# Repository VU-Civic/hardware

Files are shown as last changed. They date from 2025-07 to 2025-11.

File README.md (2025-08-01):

# CivicAlert Hardware Design Repository

This repository contains hardware design files for the CivicAlert sensor device. The design was created
using [KiCad](https://www.kicad.org/download) and requires v9.0.0 or later to open and edit.

The CivicAlert gunshot sensor is a self-contained PCB which utilizes four audio channels, a digital
compass and IMU, GNSS satellite data, and a state-of-the-art AI-based classification model to detect
gunshots in its vicinity. Relevant event information and evidential audio clips can be transferred to
a cloud server for futher processing using a dedicated cellular-based Internet of Things (IoT) network.

## Getting Started

1. Clone this repo on your local machine
2. Download and install [KiCad](https://www.kicad.org/download)
3. Open KiCad
4. Click `File->Open Project`
5. Select `hw.kicad_pro` from the repo root directory

You will be presented with a listing of available KiCad tools for this project. The two most relevant are
the "Schematic Editor" and the "PCB Editor". The Schematic Editor allows you to view and manipulate the
logical connections between hardware components and power networks, while the "PCB Editor" allows you to
view the actual design of the board and layout of the components as they will be placed during
manufacturing and assembly.

The schematic symbols and footprints for all parts and components used in this design have been stored
within the repo itself and should automatically be picked up by KiCad when you open the project. If you
would like to add new parts or alter existing ones, you may use the "Symbol Editor" or "Footprint
Editor" tool, and ensure that any new parts are stored in either `part_symbols/` or `part_footprints/`
so that new parts will be visible and available to others in the future.

Additionally, 3D CAD models for all parts can be found in `part_3d_cads/`, which will be used by KiCad
to generate a 3D rendering of the final assembled board. Finally, all datasheets, application notes,
and relevant part-specific documentation can be in the `datasheets/` folder.

## Revisions

### Revision A
*Release Date: 03-13-2025*

Original prototype version of the hardware. Expected usage includes:

* 4 audio channels to allow computation of 3D angles of arrival
* Digital compass + IMU to align angles of arrival with a global coordinate system
* Multi-constellation GNSS receiver to ensure accurate timestamping in difficult environments
* Micro-SIM card to provide direct connectivity to Thingstream for cellular data offloading
* Event detection and angle of arrival calculations performed on primary MCU
* Event classification and validation performed using AI models on external Raspberry Pi
* Data communication between primary MCU and Raspberry Pi uses USB over internal connector
* Data communication between primary MCU and external debugging machine (PC) uses USB-C connector
* Internal switch automatically routes primary MCU output to correct USB interface depending on the
  presence or absence of a connected Raspberry Pi Compute Module
* Entire board (including Raspberry Pi) is powered from a 5V USB-C cable
* Firmware flashing requires an open-ended card edge connector from
  [Kyocera AVX](https://www.digikey.com/en/products/detail/kyocera-avx/009159010061911/11307835)
  and an STLink-V3MINIE programmer from
  [STMicroelectronics](https://www.digikey.com/en/products/detail/stmicroelectronics/STLINK-V3MINIE/16284301)

Major functionality and components are shown below:

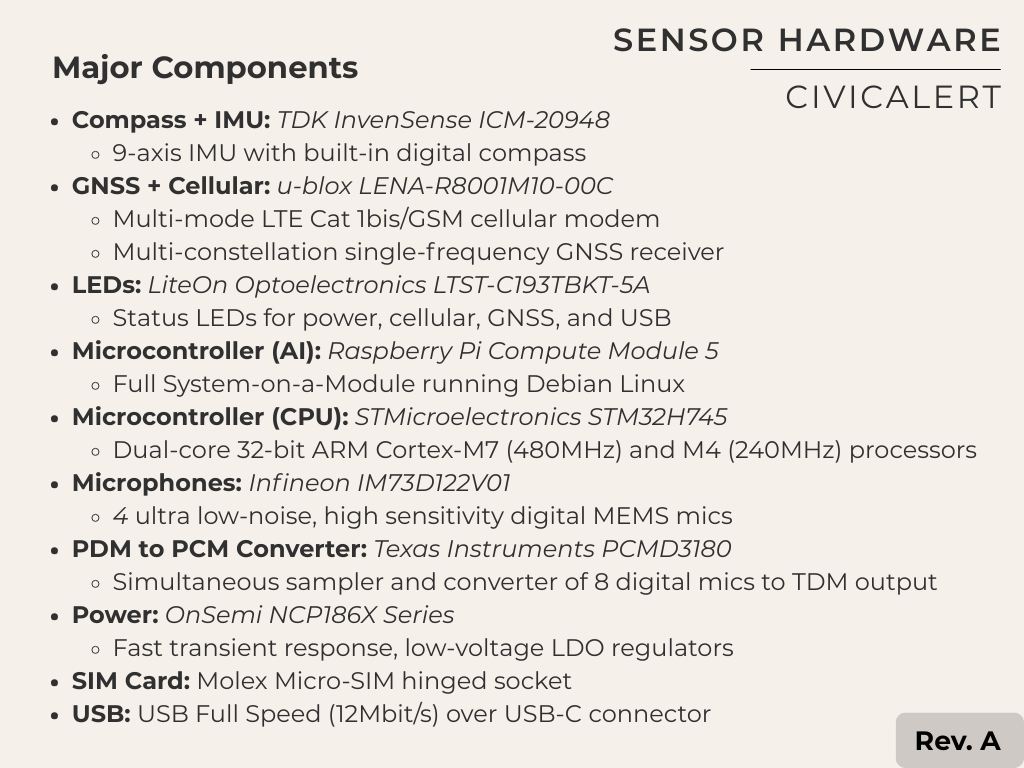
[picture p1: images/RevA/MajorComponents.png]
Rev. A Major Components

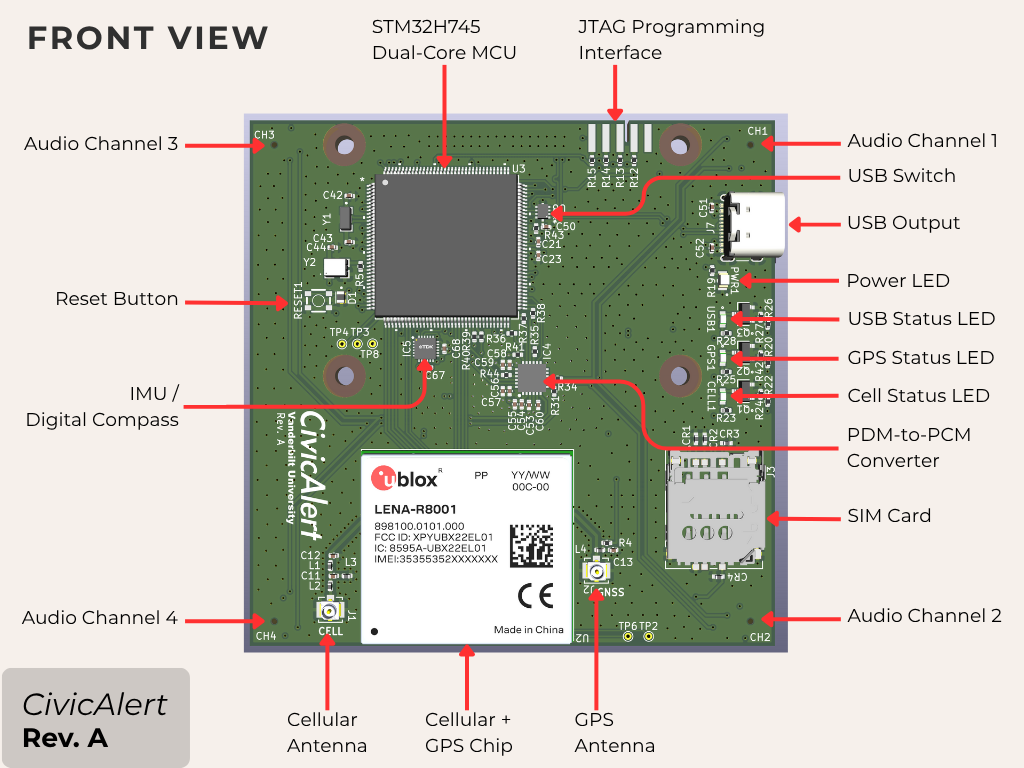
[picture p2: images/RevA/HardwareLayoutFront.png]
Rev. A Board Front

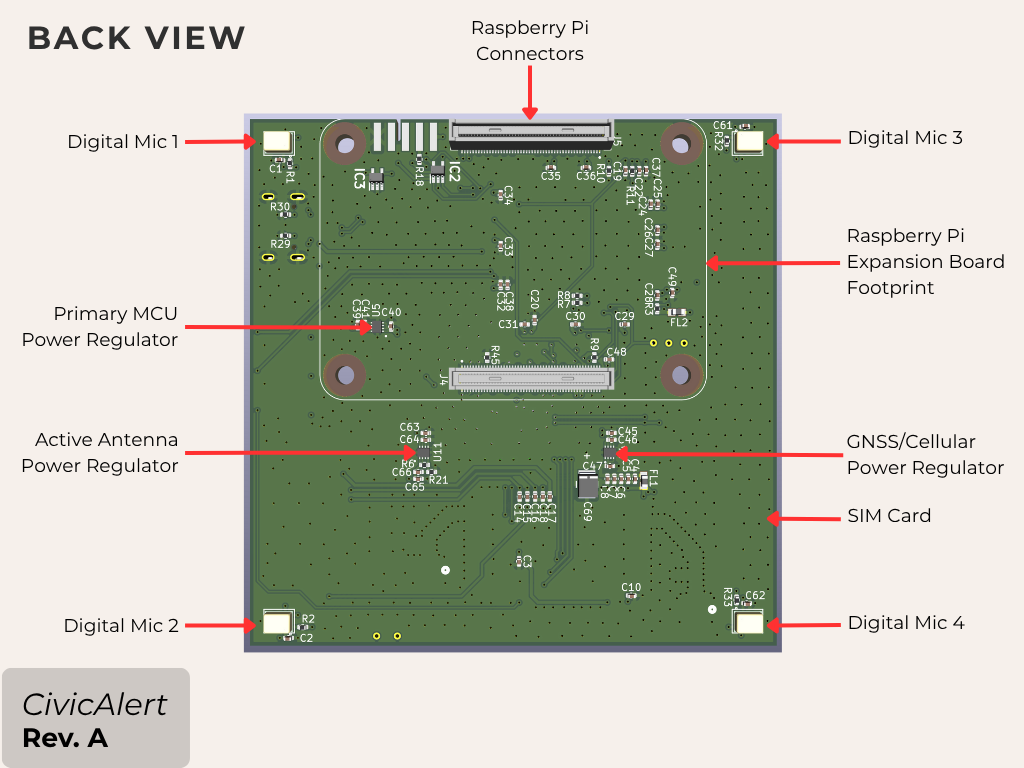
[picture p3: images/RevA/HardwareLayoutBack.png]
Rev. A Major Back Rev. A Board Back


### Revision B
*Release Date: 08-01-2025*

Updated to support edge-based AI and remove the need for an external Raspberry Pi Compute Module:

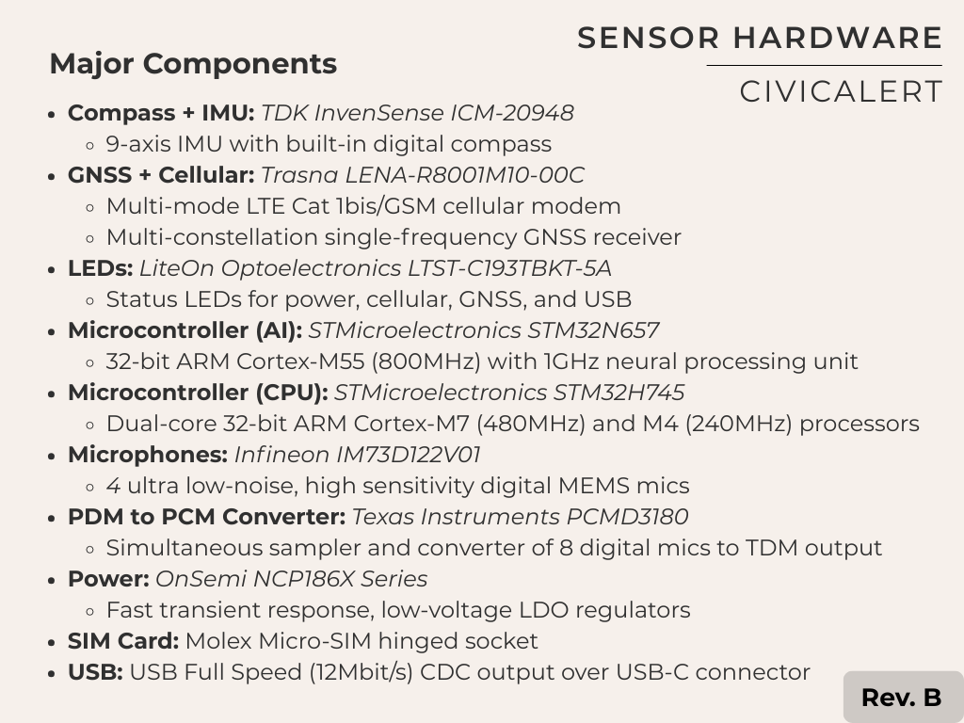
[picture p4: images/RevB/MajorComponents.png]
Rev. B Major Components

TODO: Board Designs

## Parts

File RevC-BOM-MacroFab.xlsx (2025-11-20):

Designator | Value | Footprint | Populate | MPN | Manufacturer | MPN | Manufacturer
BOOT1 | PTS810 | PTS810 | 1 | MF-SW-TACT-4.2MM | MacroFab
C1 | 6.8p | C_0402_1005Metric | 1 | GCM1555C1H6R8BA16J | Murata
C10 | 10u | C_0805_2012Metric | 1 | CGA4J1X7R0J106M125AC | TDK
C100 | 1.5p | C_0402_1005Metric | 1 | GRT1555C1H1R5CA02J | Murata
C101 | 0.5p | C_0402_1005Metric | 1 | GJM1555C1HR50WB01D | Murata
C102 | T520B337M006ATE040 | T520B337M006ATE040 | 1 | T520B337M006ATE040 | KEMET
C103 | 8.2p | C_0402_1005Metric | 1 | GRM1555C1E8R2CA01D | Murata | MF-CAP-0402-8.2pF | MacroFab
C104 | 15p | C_0402_1005Metric | 1 | GRT1555C1H150JA02J | Murata
C105 | 82p | C_0402_1005Metric | 1 | GRT1555C1H820FA02D | Murata
C106 | 10n | C_0402_1005Metric | 1 | GCM155R71H103KA55D | Murata
C107 | 0.1u | C_0402_1005Metric | 1 | GRM155R71C104KA88J | Murata | MF-CAP-0402-0.1uF | MacroFab
C108 | 0.1u | C_0402_1005Metric | 1 | GRM155R71C104KA88J | Murata | MF-CAP-0402-0.1uF | MacroFab
C109 | 0.1u | C_0402_1005Metric | 1 | GRM155R71C104KA88J | Murata | MF-CAP-0402-0.1uF | MacroFab
C11 | 10u | C_0805_2012Metric | 1 | CGA4J1X7R0J106M125AC | TDK
C110 | 0.1u | C_0402_1005Metric | 1 | GRM155R71C104KA88J | Murata | MF-CAP-0402-0.1uF | MacroFab
C111 | 0.1u | C_0402_1005Metric | 1 | GRM155R71C104KA88J | Murata | MF-CAP-0402-0.1uF | MacroFab
C112 | 0.1u | C_0402_1005Metric | 1 | GRM155R71C104KA88J | Murata | MF-CAP-0402-0.1uF | MacroFab
C113 | 10u | C_0603_1608Metric | 1 | GRM188Z71A106KA73D | Murata
C114 | 2.2u | C_0402_1005Metric | 1 | GRT155C71A225KE13D | Murata
C115 | 10u | C_0603_1608Metric | 1 | GRM188Z71A106KA73D | Murata
C116 | 0.1u | C_0402_1005Metric | 1 | GRM155R71C104KA88J | Murata | MF-CAP-0402-0.1uF | MacroFab
C117 | 0.1u | C_0402_1005Metric | 1 | GRM155R71C104KA88J | Murata | MF-CAP-0402-0.1uF | MacroFab
C118 | 10u | C_0603_1608Metric | 1 | GRM188Z71A106KA73D | Murata
C119 | 10u | C_0603_1608Metric | 1 | GRM188Z71A106KA73D | Murata
C12 | 10u | C_0805_2012Metric | 1 | CGA4J1X7R0J106M125AC | TDK
C120 | 0.1u | C_0402_1005Metric | 1 | GRM155R71C104KA88J | Murata | MF-CAP-0402-0.1uF | MacroFab
C121 | 10u | C_0603_1608Metric | 1 | GRM188Z71A106KA73D | Murata
C13 | 1n | C_0402_1005Metric | 1 | GRM155R71H102JA01J | Murata | MF-CAP-0402-1nF | MacroFab
C14 | 10u | C_0603_1608Metric | 1 | GRM188Z71A106KA73D | Murata
C15 | 10u | C_0603_1608Metric | 1 | GRM188Z71A106KA73D | Murata
C16 | 0.1u | C_0402_1005Metric | 1 | GRM155R71C104KA88J | Murata | MF-CAP-0402-0.1uF | MacroFab
C17 | 10u | C_0603_1608Metric | 1 | GRM188Z71A106KA73D | Murata
C18 | 0.1u | C_0402_1005Metric | 1 | GRM155R71C104KA88J | Murata | MF-CAP-0402-0.1uF | MacroFab
C19 | 10u | C_0603_1608Metric | 1 | GRM188Z71A106KA73D | Murata
C2 | 4.7p | C_0402_1005Metric | 1 | GCM1555C1H4R7CA16D | Murata
C20 | 10u | C_0603_1608Metric | 1 | GRM188Z71A106KA73D | Murata
C21 | 0.1u | C_0402_1005Metric | 1 | GRM155R71C104KA88J | Murata | MF-CAP-0402-0.1uF | MacroFab
C22 | 10u | C_0603_1608Metric | 1 | GRM188Z71A106KA73D | Murata
C23 | 10u | C_0603_1608Metric | 1 | GRM188Z71A106KA73D | Murata
C24 | 0.1u | C_0402_1005Metric | 1 | GRM155R71C104KA88J | Murata | MF-CAP-0402-0.1uF | MacroFab
C25 | 10u | C_0603_1608Metric | 1 | GRM188Z71A106KA73D | Murata
C26 | 0.1u | C_0201_0603Metric | 1 | GRM033Z71C104KE14D | Murata
C27 | 0.1u | C_0201_0603Metric | 1 | GRM033Z71C104KE14D | Murata
C28 | 0.1u | C_0201_0603Metric | 1 | GRM033Z71C104KE14D | Murata
C29 | 0.1u | C_0201_0603Metric | 1 | GRM033Z71C104KE14D | Murata
C3 | 10u | C_0805_2012Metric | 1 | CGA4J1X7R0J106M125AC | TDK
C30 | 2.2u | C_0201_0603Metric | 1 | GRT033D70J105ME13D | Murata
C31 | 0.1u | C_0201_0603Metric | 1 | GRM033Z71C104KE14D | Murata
C32 | 0.1u | C_0201_0603Metric | 1 | GRM033Z71C104KE14D | Murata
C33 | 0.1u | C_0201_0603Metric | 1 | GRM033Z71C104KE14D | Murata
C34 | 0.1u | C_0201_0603Metric | 1 | GRM033Z71C104KE14D | Murata
C35 | 0.1u | C_0201_0603Metric | 1 | GRM033Z71C104KE14D | Murata
C36 | 0.1u | C_0201_0603Metric | 1 | GRM033Z71C104KE14D | Murata
C37 | 0.1u | C_0201_0603Metric | 1 | GRM033Z71C104KE14D | Murata
C38 | 0.1u | C_0201_0603Metric | 1 | GRM033Z71C104KE14D | Murata
C39 | 2.2u | C_0201_0603Metric | 1 | GRT033D70J105ME13D | Murata
C4 | 10u | C_0805_2012Metric | 1 | CGA4J1X7R0J106M125AC | TDK
C40 | 2.2u | C_0201_0603Metric | 1 | GRT033D70J105ME13D | Murata
C41 | 2.2u | C_0201_0603Metric | 1 | GRT033D70J105ME13D | Murata
C42 | 2.2u | C_0201_0603Metric | 1 | GRT033D70J105ME13D | Murata
C43 | 2.2u | C_0201_0603Metric | 1 | GRT033D70J105ME13D | Murata
C44 | 4.7u | C_0402_1005Metric | 1 | GRT155D70J475ME13D | Murata
C45 | 0.1u | C_0201_0603Metric | 1 | GRM033Z71C104KE14D | Murata
C46 | 0.1u | C_0201_0603Metric | 1 | GRM033Z71C104KE14D | Murata
C5 | 10u | C_0805_2012Metric | 1 | CGA4J1X7R0J106M125AC | TDK
C51 | 0.1u | C_0402_1005Metric | 1 | GRM155R71C104KA88J | Murata | MF-CAP-0402-0.1uF | MacroFab
C52 | 4.7u | C_0402_1005Metric | 1 | GRT155D70J475ME13D | Murata
C53 | 4.7u | C_0402_1005Metric | 1 | GRT155D70J475ME13D | Murata
C54 | 0.1u | C_0402_1005Metric | 1 | GRM155R71C104KA88J | Murata | MF-CAP-0402-0.1uF | MacroFab
C55 | 0.1u | C_0402_1005Metric | 1 | GRM155R71C104KA88J | Murata | MF-CAP-0402-0.1uF | MacroFab
C56 | 4.7u | C_0402_1005Metric | 1 | GRT155D70J475ME13D | Murata
C57 | 0.1u | C_0402_1005Metric | 1 | GRM155R71C104KA88J | Murata | MF-CAP-0402-0.1uF | MacroFab
C58 | 10u | C_0603_1608Metric | 1 | GRM188Z71A106KA73D | Murata
C59 | 0.1u | C_0402_1005Metric | 1 | GRM155R71C104KA88J | Murata | MF-CAP-0402-0.1uF | MacroFab
C6 | 47u | C_1206_3216Metric | 1 | C3216X7S0J476M160AC | TDK
C60 | 2.2u | C_0402_1005Metric | 1 | GRT155C71A225KE13D | Murata
C61 | 10u | C_0603_1608Metric | 1 | GRM188Z71A106KA73D | Murata
C62 | 4.7u | C_0402_1005Metric | 1 | GRT155D70J475ME13D | Murata
C63 | 0.1u | C_0402_1005Metric | 1 | GRM155R71C104KA88J | Murata | MF-CAP-0402-0.1uF | MacroFab
C64 | 0.1u | C_0402_1005Metric | 1 | GRM155R71C104KA88J | Murata | MF-CAP-0402-0.1uF | MacroFab
C65 | 0.1u | C_0402_1005Metric | 1 | GRM155R71C104KA88J | Murata | MF-CAP-0402-0.1uF | MacroFab
C66 | 0.1u | C_0402_1005Metric | 1 | GRM155R71C104KA88J | Murata | MF-CAP-0402-0.1uF | MacroFab
C67 | 0.1u | C_0402_1005Metric | 1 | GRM155R71C104KA88J | Murata | MF-CAP-0402-0.1uF | MacroFab
C68 | 0.1u | C_0402_1005Metric | 1 | GRM155R71C104KA88J | Murata | MF-CAP-0402-0.1uF | MacroFab
C69 | 0.1u | C_0402_1005Metric | 1 | GRM155R71C104KA88J | Murata | MF-CAP-0402-0.1uF | MacroFab
C7 | 10u | C_0805_2012Metric | 1 | CGA4J1X7R0J106M125AC | TDK
C70 | 0.1u | C_0402_1005Metric | 1 | GRM155R71C104KA88J | Murata | MF-CAP-0402-0.1uF | MacroFab
C71 | 0.1u | C_0402_1005Metric | 1 | GRM155R71C104KA88J | Murata | MF-CAP-0402-0.1uF | MacroFab
C72 | 0.1u | C_0402_1005Metric | 1 | GRM155R71C104KA88J | Murata | MF-CAP-0402-0.1uF | MacroFab
C73 | 0.1u | C_0402_1005Metric | 1 | GRM155R71C104KA88J | Murata | MF-CAP-0402-0.1uF | MacroFab
C74 | 0.1u | C_0402_1005Metric | 1 | GRM155R71C104KA88J | Murata | MF-CAP-0402-0.1uF | MacroFab
C75 | 0.1u | C_0402_1005Metric | 1 | GRM155R71C104KA88J | Murata | MF-CAP-0402-0.1uF | MacroFab
C76 | 4.7u | C_0402_1005Metric | 1 | GRT155D70J475ME13D | Murata
C77 | 0.1u | C_0402_1005Metric | 1 | GRM155R71C104KA88J | Murata | MF-CAP-0402-0.1uF | MacroFab
C78 | 2.2u | C_0402_1005Metric | 1 | GRT155C71A225KE13D | Murata
C79 | 4.7u | C_0402_1005Metric | 1 | GRT155D70J475ME13D | Murata
C8 | 47u | C_1206_3216Metric | 1 | C3216X7S0J476M160AC | TDK
C80 | 2.2u | C_0402_1005Metric | 1 | GRT155C71A225KE13D | Murata
C81 | 2.2u | C_0402_1005Metric | 1 | GRT155C71A225KE13D | Murata
C82 | 10n | C_0402_1005Metric | 1 | GCM155R71H103KA55D | Murata
C83 | 0.1u | C_0402_1005Metric | 1 | GRM155R71C104KA88J | Murata | MF-CAP-0402-0.1uF | MacroFab
C84 | 3.3p | C_0402_1005Metric | 1 | GRT1555C1H3R3CA02J | Murata
C85 | 0.1u | C_0402_1005Metric | 1 | GRM155R71C104KA88J | Murata | MF-CAP-0402-0.1uF | MacroFab
C86 | 3.3p | C_0402_1005Metric | 1 | GRT1555C1H3R3CA02J | Murata
C87 | 0.1u | C_0402_1005Metric | 1 | GRM155R71C104KA88J | Murata | MF-CAP-0402-0.1uF | MacroFab
C88 | 0.1u | C_0402_1005Metric | 1 | GRM155R71C104KA88J | Murata | MF-CAP-0402-0.1uF | MacroFab
C89 | 0.1u | C_0402_1005Metric | 1 | GRM155R71C104KA88J | Murata | MF-CAP-0402-0.1uF | MacroFab
C9 | 10u | C_0805_2012Metric | 1 | CGA4J1X7R0J106M125AC | TDK
C90 | 0.1u | C_0402_1005Metric | 1 | GRM155R71C104KA88J | Murata | MF-CAP-0402-0.1uF | MacroFab
C91 | 0.1u | C_0402_1005Metric | 1 | GRM155R71C104KA88J | Murata | MF-CAP-0402-0.1uF | MacroFab
C92 | 0.1u | C_0402_1005Metric | 1 | GRM155R71C104KA88J | Murata | MF-CAP-0402-0.1uF | MacroFab
C93 | 0.1u | C_0402_1005Metric | 1 | GRM155R71C104KA88J | Murata | MF-CAP-0402-0.1uF | MacroFab
C94 | 0.1u | C_0402_1005Metric | 1 | GRM155R71C104KA88J | Murata | MF-CAP-0402-0.1uF | MacroFab
C95 | 47p | C_0402_1005Metric | 1 | GRT1555C1H470JA02J | Murata
C96 | 47p | C_0402_1005Metric | 1 | GRT1555C1H470JA02J | Murata
C97 | 47p | C_0402_1005Metric | 1 | GRT1555C1H470JA02J | Murata
C98 | 47p | C_0402_1005Metric | 1 | GRT1555C1H470JA02J | Murata
C99 | 0.1u | C_0402_1005Metric | 1 | GRM155R71C104KA88J | Murata | MF-CAP-0402-0.1uF | MacroFab
CELL1 | LTST-C190KGKT | LTST-C190KGKT | 1 | MF-LED-0603-GREEN | MacroFab
CELL2 | RECE.20279.001E.01 | RECE.20279.001E.01 | 1 | RECE.20279.001E.01 | Taoglas
CH1 | SPK11R1LM4H-1 | SPK11R1LM4H-1 | 1 | SPK11R1LM4H-1 | Syntiant
CH2 | SPK11R1LM4H-1 | SPK11R1LM4H-1 | 1 | SPK11R1LM4H-1 | Syntiant
CH3 | SPK11R1LM4H-1 | SPK11R1LM4H-1 | 1 | SPK11R1LM4H-1 | Syntiant
CH4 | SPK11R1LM4H-1 | SPK11R1LM4H-1 | 1 | SPK11R1LM4H-1 | Syntiant
CR1 | BAT854W,115 | BAT854AW,115 | 1 | BAT854W,115 | Nexperia
CR2 | PESD0402-140 | PESD0402-140_LTF | 1 | PESD0402-140 | Littelfuse
CR3 | PESD0402-140 | PESD0402-140_LTF | 1 | PESD0402-140 | Littelfuse
CR4 | PESD0402-140 | PESD0402-140_LTF | 1 | PESD0402-140 | Littelfuse
CR5 | PESD0402-140 | PESD0402-140_LTF | 1 | PESD0402-140 | Littelfuse
CR6 | BAT854W,115 | BAT854AW,115 | 1 | BAT854W,115 | Nexperia
FL1 | FCM 1608KF-601T03 | FCM1608KF-601T03 | 1 | FCM 1608KF-601T03 | Tai Tech
FL2 | BLM18EG221SN1D | BLM18EG221SN1D | 1 | BLM18EG221SN1D | Murata
GNSS1 | RECE.20279.001E.01 | RECE.20279.001E.01 | 1 | RECE.20279.001E.01 | Taoglas
GPS1 | LTST-C190KGKT | LTST-C190KGKT | 1 | MF-LED-0603-GREEN | MacroFab
IC1 | MX25UM25645GXDI00-T | MX25UM25645GXDI00 | 1 | MX25UM25645GXDI00-T | Macronix
IC2 | ESDALC6V1W5 | ESDALC6V1W5 | 1 | ESDALC6V1W5 | STMicroelectronics
IC3 | ESDALC6V1W5 | ESDALC6V1W5 | 1 | ESDALC6V1W5 | STMicroelectronics
IC4 | ICM-20948 | ICM-20948 | 1 | ICM-20948 | InvenSense
J1 | USB4730-GF-A_REVA | USB4730-GF-A | 1 | USB4730-GF-A-KIT | Global Connector Technology
J2 | 78800-0001 | 0788000001 | 1 | 78800-0001 | Molex
L1 | IHLP1212BZERR88M11 | IHLP1212BZERR88M11 | 1 | IHLP1212BZERR88M11 | Vishay
L2 | IHLP1212BZER1R5M11 | IHLP1212BZER1R5M11 | 1 | IHLP1212BZER1R5M11 | Vishay
L3 | 120n | L_0402_1005Metric | 1 | LQW15ANR12J00 | Murata | LQW15ANR12J00D | Murata
L4 | 3.4n | L_0402_1005Metric | 1 | LQG15WZ3N4S02D | Murata
L5 | 2.7n | L_0402_1005Metric | 1 | LQG15HS2N7B02D | Murata
L6 | 1.2n | L_0402_1005Metric | 1 | LQG15HS1N2B02D | Murata
PWR1 | LTST-C190KGKT | LTST-C190KGKT | 1 | MF-LED-0603-GREEN | MacroFab
Q3 | MMBT3904LT3G | MMBT3904LT3G | 1 | BC847CE6327HTSA1 | Infineon
Q4 | MMBT3904LT3G | MMBT3904LT3G | 1 | BC847CE6327HTSA1 | Infineon
R10 | 300 | R_0402_1005Metric | 1 | MF-RES-0402-330 | MacroFab
R11 | 10k | R_0402_1005Metric | 1 | MF-RES-0402-10K | MacroFab
R12 | 22 | R_0402_1005Metric | 1 | MF-RES-0402-22 | MacroFab
R13 | 10k | R_0402_1005Metric | 1 | MF-RES-0402-10K | MacroFab
R14 | 10k | R_0402_1005Metric | 1 | MF-RES-0402-10K | MacroFab
R15 | 10k | R_0402_1005Metric | 1 | MF-RES-0402-10K | MacroFab
R16 | 10k | R_0402_1005Metric | 1 | MF-RES-0402-10K | MacroFab
R17 | 10k | R_0402_1005Metric | 1 | MF-RES-0402-10K | MacroFab
R18 | 22 | R_0402_1005Metric | 1 | MF-RES-0402-22 | MacroFab
R19 | 22 | R_0402_1005Metric | 1 | MF-RES-0402-22 | MacroFab
R20 | 47k | R_0402_1005Metric | 1 | CRGCQ0402F47K | TE Connectivity
R21 | 10k | R_0402_1005Metric | 1 | MF-RES-0402-10K | MacroFab
R22 | 47k | R_0402_1005Metric | 1 | CRGCQ0402F47K | TE Connectivity
R23 | 47k | R_0402_1005Metric | 1 | CRGCQ0402F47K | TE Connectivity
R24 | 47k | R_0402_1005Metric | 1 | CRGCQ0402F47K | TE Connectivity
R25 | 47k | R_0402_1005Metric | 1 | CRGCQ0402F47K | TE Connectivity
R26 | 100k | R_0402_1005Metric | 1 | MF-RES-0402-100K | MacroFab
R27 | 10k | R_0402_1005Metric | 1 | MF-RES-0402-10K | MacroFab
R28 | 47 | R_0402_1005Metric | 1 | MF-RES-0402-47 | MacroFab
R3 | 226k | R_0603_1608Metric | 1 | RT0603BRD07226KL | Yageo Group
R32 | 22 | R_0402_1005Metric | 1 | MF-RES-0402-22 | MacroFab
R33 | 47 | R_0402_1005Metric | 1 | MF-RES-0402-47 | MacroFab
R34 | 22 | R_0402_1005Metric | 1 | MF-RES-0402-22 | MacroFab
R35 | 47 | R_0402_1005Metric | 1 | MF-RES-0402-47 | MacroFab
R36 | 10k | R_0402_1005Metric | 1 | MF-RES-0402-10K | MacroFab
R37 | 10k | R_0402_1005Metric | 1 | MF-RES-0402-10K | MacroFab
R38 | 22 | R_0402_1005Metric | 1 | MF-RES-0402-22 | MacroFab
R39 | 22 | R_0402_1005Metric | 1 | MF-RES-0402-22 | MacroFab
R40 | 22 | R_0402_1005Metric | 1 | MF-RES-0402-22 | MacroFab
R41 | 5.1k | R_0402_1005Metric | 1 | RC0402FR-075K1L | Yageo Group
R42 | 5.1k | R_0402_1005Metric | 1 | RC0402FR-075K1L | Yageo Group
R43 | 2.2k | R_0402_1005Metric | 1 | 3-1622826-1 | TE Connectivity / AMP | CR0402-FX-2201GLF | Bourns
R44 | 2.2k | R_0402_1005Metric | 1 | 3-1622826-1 | TE Connectivity / AMP | CR0402-FX-2201GLF | Bourns
R45 | 10k | R_0402_1005Metric | 1 | MF-RES-0402-10K | MacroFab
R46 | 300 | R_0402_1005Metric | 1 | MF-RES-0402-330 | MacroFab
R47 | 10k | R_0402_1005Metric | 1 | MF-RES-0402-10K | MacroFab
R48 | 47k | R_0402_1005Metric | 1 | CRGCQ0402F47K | TE Connectivity
R49 | 33 | R_0402_1005Metric | 1 | AC0402JR-0733RL | Yageo Group
R5 | 143k | R_0603_1608Metric | 1 | RT0603BRD07140KL | Yageo Group
R50 | 300 | R_0402_1005Metric | 1 | MF-RES-0402-330 | MacroFab
R51 | 10k | R_0402_1005Metric | 1 | MF-RES-0402-10K | MacroFab
R52 | 47k | R_0402_1005Metric | 1 | CRGCQ0402F47K | TE Connectivity
R53 | 47 | R_0402_1005Metric | 1 | MF-RES-0402-47 | MacroFab
R54 | 47 | R_0402_1005Metric | 1 | MF-RES-0402-47 | MacroFab
R55 | 47 | R_0402_1005Metric | 1 | MF-RES-0402-47 | MacroFab
R56 | 47 | R_0402_1005Metric | 1 | MF-RES-0402-47 | MacroFab
R57 | 47 | R_0402_1005Metric | 1 | MF-RES-0402-47 | MacroFab
R58 | 22 | R_0402_1005Metric | 1 | MF-RES-0402-22 | MacroFab
R59 | 22 | R_0402_1005Metric | 1 | MF-RES-0402-22 | MacroFab
R6 | 97.6k | R_0603_1608Metric | 1 | RT0603BRD0797K6L | Yageo Group
R60 | 2.2k | R_0402_1005Metric | 1 | 3-1622826-1 | TE Connectivity / AMP | CR0402-FX-2201GLF | Bourns
R61 | 2.2k | R_0402_1005Metric | 1 | 3-1622826-1 | TE Connectivity / AMP | CR0402-FX-2201GLF | Bourns
R62 | 10k | R_0402_1005Metric | 1 | MF-RES-0402-10K | MacroFab
R63 | 2.2k | R_0402_1005Metric | 1 | 3-1622826-1 | TE Connectivity / AMP | CR0402-FX-2201GLF | Bourns
R64 | 2.2k | R_0402_1005Metric | 1 | 3-1622826-1 | TE Connectivity / AMP | CR0402-FX-2201GLF | Bourns
R7 | 261k | R_0603_1608Metric | 1 | RT0603BRD07261KL | Yageo Group
R8 | 62k | R_0402_1005Metric | 1 | ERJ-2RKF6202X | Panasonic
R9 | 91k | R_0402_1005Metric | 1 | ERJ-2RKF9102X | Panasonic
SD1 | 15882 | 15882 | 1 | MF-MICROSD | MacroFab
U1 | LTC3315AHV-TRMPBF | LTC3315AHV | 1 | LTC3315AHV#TRMPBF | Analog Devices
U10 | TPS22919DCKR | TPS22919DCKR | 1 | TPS22919DCKR | Texas Instruments
U11 | STM32H745ZIT6 | STM32H745ZIT6 | 1 | STM32H745ZIT6 | STMicroelectronics
U12 | LENA-R8001M10-00C | LENA-R8001M10-00C | 1 | LENA-R8001M10-00C | u-blox
U13 | PCMD3140IRTER | PCMD3140IRTER | 1 | PCMD3140IRTER | Texas Instruments
U14 | NCP186AMX180TAG | NCP186AMX | 1 | NCP186AMX180TAG | onsemi
U2 | NCP186AMX180TAG | NCP186AMX | 1 | NCP186AMX180TAG | onsemi
U3 | NCP186AMX390TAG | NCP186AMX | 1 | NCP186AMX390TAG | onsemi
U4 | NCP186AMX180TAG | NCP186AMX | 1 | NCP186AMX180TAG | onsemi
U5 | NCP186AMX330TAG | NCP186AMX | 1 | NCP186AMX330TAG | onsemi
U6 | STM32N647L0H3Q | STM32N647L0H3Q | 1 | STM32N647L0H3Q | STMicroelectronics
U7 | HSP051-4M10 | HSP051-4M10 | 1 | HSP051-4M10 | STMicroelectronics
U8 | HSP051-4M10 | HSP051-4M10 | 1 | HSP051-4M10 | STMicroelectronics
U9 | NX3L1T3157GMZ | NX3L1T3157GMZ | 1 | NX3L1T3157GMZ | NXP Semiconductors
Y3 | ATX-H11-F-25.000MHz-F25-T | ATX-H11-F-25_000MHz-F25-T | 1 | ATX-H11-F-25.000MHZ-F25-T | Abracon
Y4 | ABS07AIG-32.768KHZ-7-T | ABS07AIG_32_768KHZ_7_T | 1 | ABS07AIG-32.768KHZ-7-T | Abracon

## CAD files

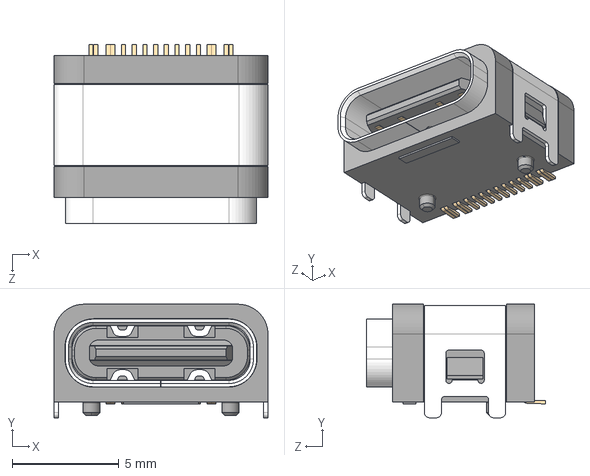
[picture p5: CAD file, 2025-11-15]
part_3d_cads/USB4730-GF-A.step
10.0 x 5.31 x 8.36 mm

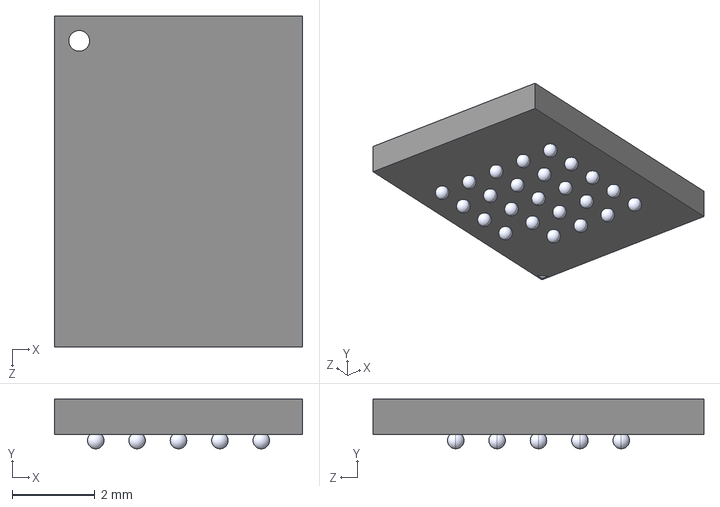
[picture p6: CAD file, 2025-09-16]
part_3d_cads/MX25UM25645GXDI00.step
6.00 x 1.20 x 8.00 mm

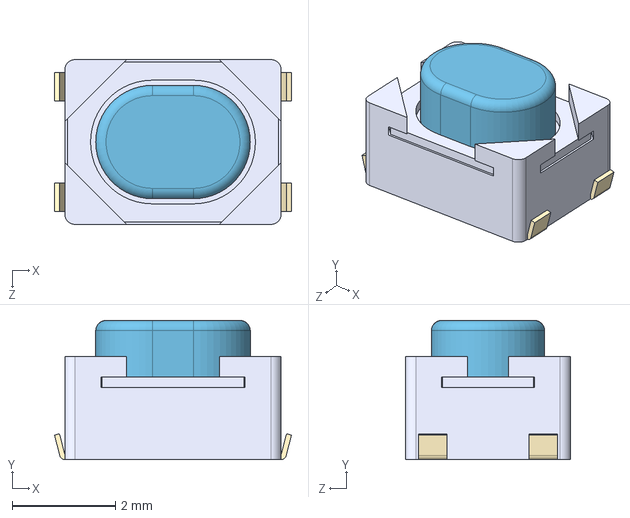
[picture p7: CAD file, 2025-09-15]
part_3d_cads/PTS810S.step
4.60 x 2.70 x 3.20 mm

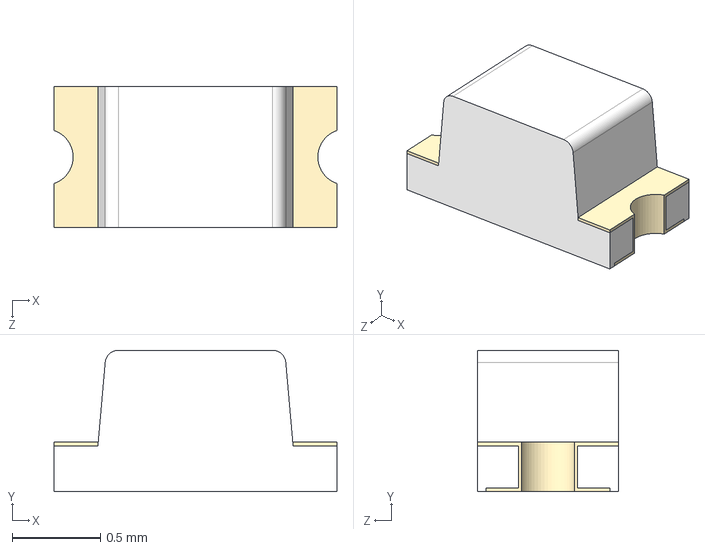
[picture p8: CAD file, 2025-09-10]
part_3d_cads/LTST-C190KGKT.step
1.60 x 0.8 x 0.8 mm

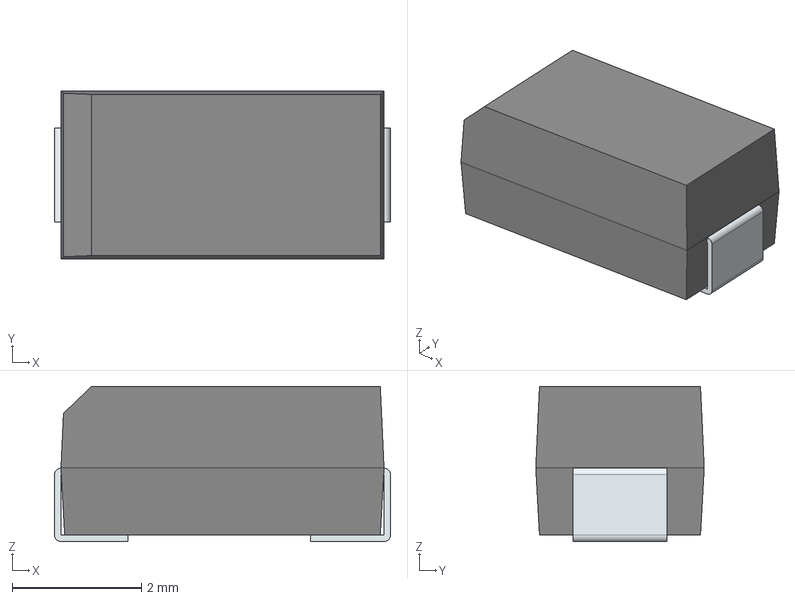
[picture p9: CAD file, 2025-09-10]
part_3d_cads/B140Q-13-F.step
5.20 x 2.60 x 2.40 mm
FilletPin1
FilletPin2

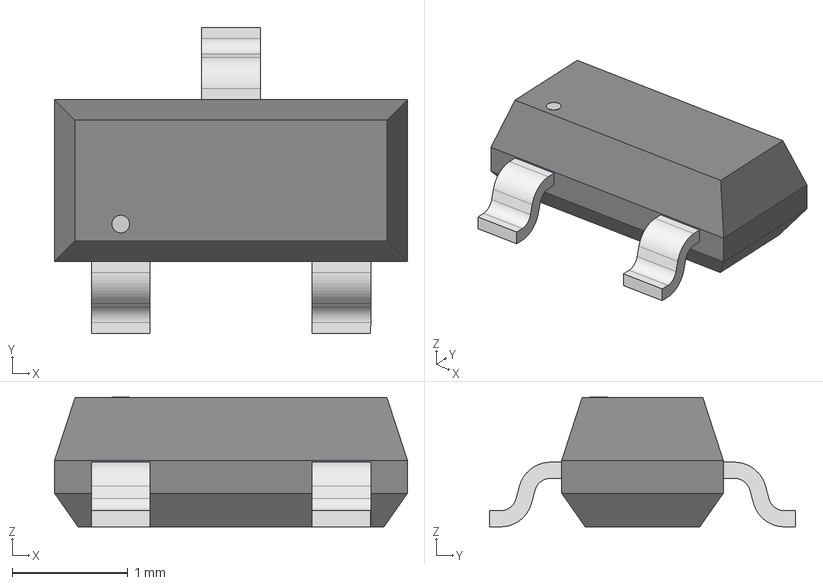
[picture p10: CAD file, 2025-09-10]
part_3d_cads/MMBT3904LT3G.step
3.05 x 2.64 x 1.12 mm

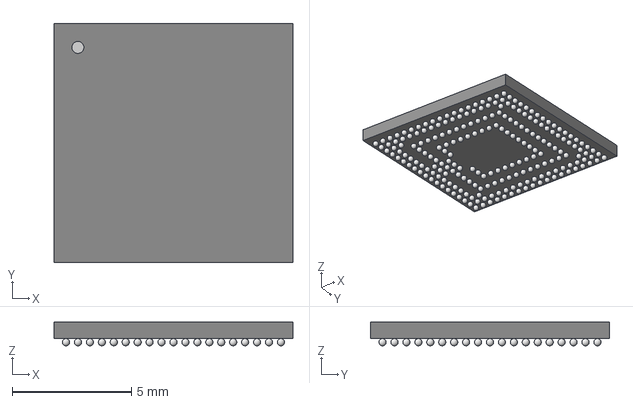
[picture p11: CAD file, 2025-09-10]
part_3d_cads/STM32N647L0H3Q.step
10.0 x 10.0 x 0.993 mm

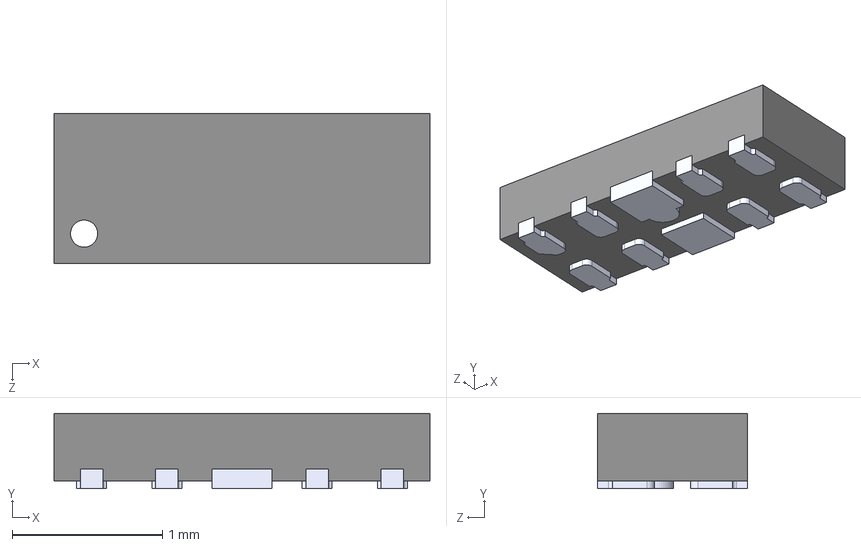
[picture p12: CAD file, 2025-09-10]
part_3d_cads/HSP051-4M10.step
2.50 x 0.5 x 1.00 mm

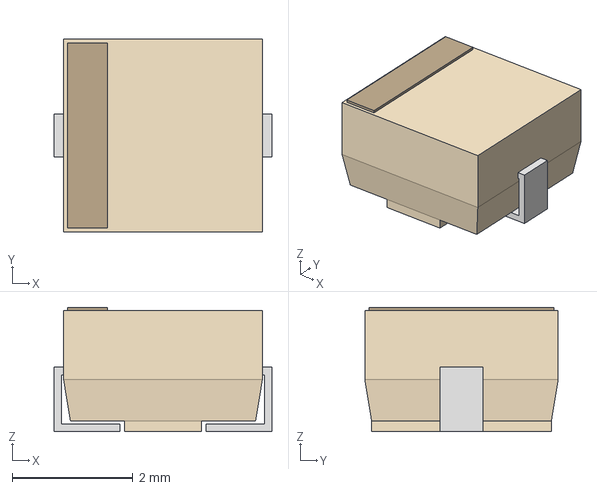
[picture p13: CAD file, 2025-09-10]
part_3d_cads/IHLP1212BZERR88M11.step
3.61 x 3.20 x 2.06 mm

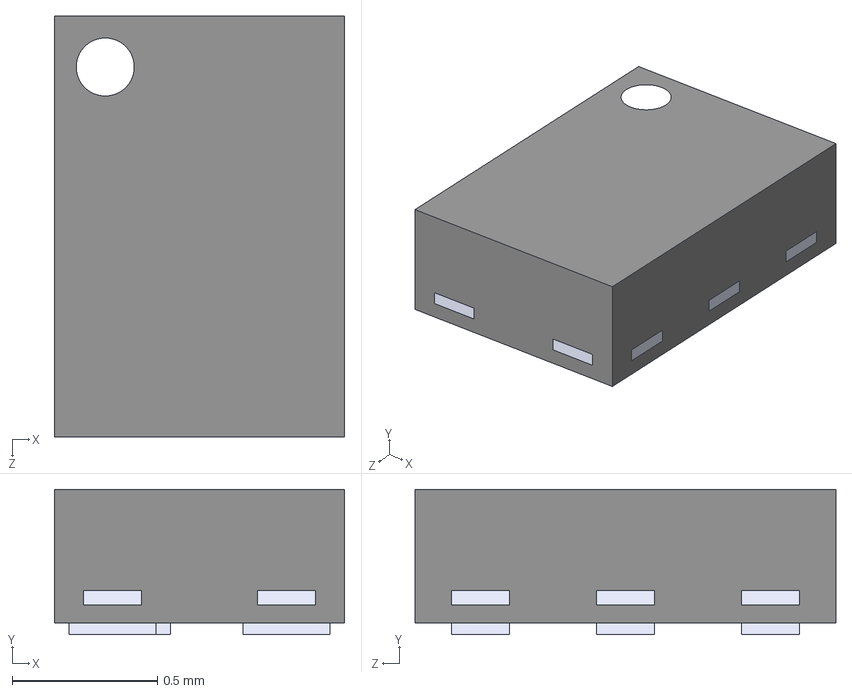
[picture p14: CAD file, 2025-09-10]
part_3d_cads/NX3L1T3157GMZ.step
1 x 0.5 x 1.45 mm

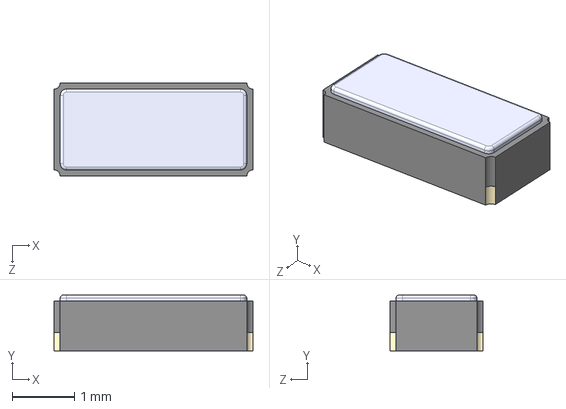
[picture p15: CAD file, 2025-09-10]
part_3d_cads/ABS07AIG-32.768KHZ-7-T.step
3.20 x 0.9 x 1.50 mm

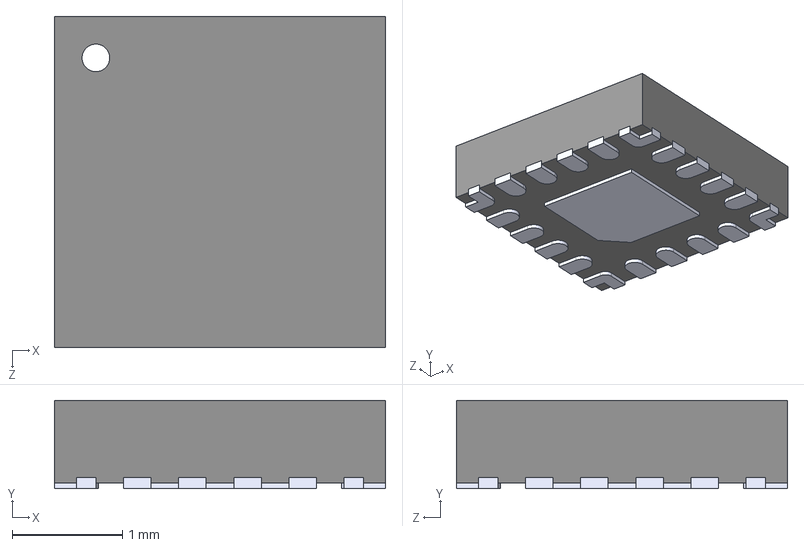
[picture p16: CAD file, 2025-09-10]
part_3d_cads/PCMD3140IRTER.step
3.00 x 0.8 x 3.00 mm

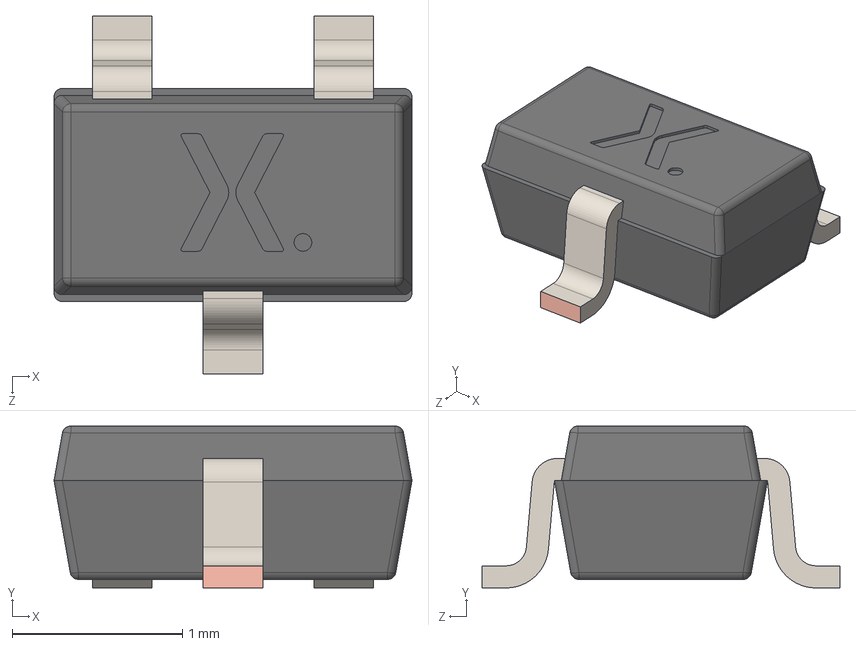
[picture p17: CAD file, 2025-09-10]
part_3d_cads/BAT854AW,115.step
2.10 x 0.95 x 2.10 mm
Upper body
lower body
Lead x 3

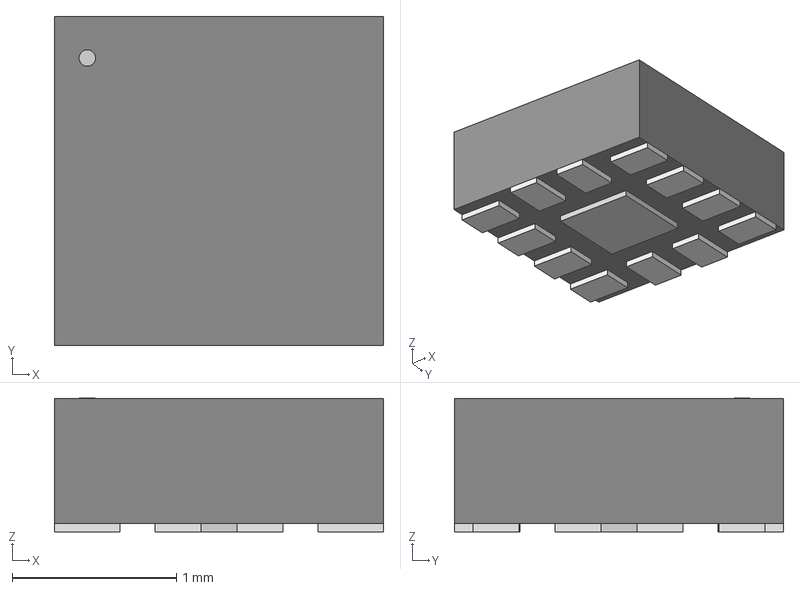
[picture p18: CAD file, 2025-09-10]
part_3d_cads/LTC3315AHV.step
2.01 x 2.01 x 0.815 mm

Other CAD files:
part_3d_cads/IHLP1212BZER1R5M11.step
part_3d_cads/NCP186AMX180TAG.step
part_3d_cads/KC2016Z48.0000C15XXK.step
part_3d_cads/NCP186AMX330TAG.step
part_3d_cads/0788000001.step
part_3d_cads/15882.step
part_3d_cads/ATX-H11-F-25_000MHz-F25-T.step
part_3d_cads/BC847CE6327HTSA1.step
part_3d_cads/BLM18EG221SN1D.step
part_3d_cads/ESDALC6V1W5.step
part_3d_cads/FCM1608KF-601T03.step
part_3d_cads/ICM-20948.step
part_3d_cads/IM73D122V01XTMA1.step
part_3d_cads/NCP186AMX390TAG.step
part_3d_cads/NCP186BMX185TAG.step
part_3d_cads/PESD0402-140_LTF.step
part_3d_cads/RECE.20279.001E.01.step
part_3d_cads/SGECL01-01-1000.step
part_3d_cads/STM32H745ZIT6.step
part_3d_cads/T520B337M006ATE040.step
part_3d_cads/TPS22919DCKR.step

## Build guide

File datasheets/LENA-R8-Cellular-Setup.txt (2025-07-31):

# SET CONNECTION DURATION = 15 MINUTES (SERVER WILL DISCONNECT FROM CLIENT AFTER 22.5 MINUTES OF NOT RECEIVING A PINGREQ)
# CLIENTS SEND PINGREQ EVERY 15 MINUTES (UPON RECEIPT AT SERVER, UPDATE LAST SEEN TIME FOR THAT DEVICE IN DYNAMODB)
# THIS ALLOWS:
#    IMMEDIATE BIDIRECTIONAL COMMUNICATION IF NETWORK CONNECTIVITY IS MAINTAINED
#    AT MOST 15 MINUTES OF DELAY BETWEEN SENDING A MESSAGE FROM BROKER TO DEVICE
#    GUARANTEED DELIVERY OF MESSAGES AT LEAST ONCE
# TEST IF A CLIENT THAT HAS LOST A CONNECTION AND ATTEMPTS TO RECONNECT TO THE BROKER (WHO DOESN'T KNOW THAT THE ORIGINAL CONNECTION WAS LOST) IS ALLOWED TO CONNECT/TAKEOVER THE OLD CONNECTION (IF NOT, WE NEED TO SHORTEN THE CONNECTION DURATION TIMEOUT)
# EXPECTED MESSAGES PER MONTH PER DEVICE:
#    PING EVERY 15 MINUTES (1 PINGREQ + 1 PINGACK = 2 MESSAGES)
#    SEND DEVICE STATS EVERY 15 MINUTES WITH QOS = 0 (1 MESSAGE) - maybe only send if parameters have changed send last send
#    ASSUME 4 ALERTS PER HOUR (1 PUBLISH + 1 PUBACK FOR METADATA [QOS = 1] + 18 PUBLISH FOR 17KB OF AUDIO DATA [QOS = 0] (max message payload is 1016 bytes), 20 MESSAGES)
#    THEREFORE, PER HOUR = 92 MESSAGES, PER DAY = 2,208 MESSAGES, PER MONTH = 68,448 MESSAGES (@ $2 PER 12,000, THEREFORE $12/MONTH/DEVICE)

PLAY AROUND WITH USING QOS = 0 FOR ALERTS AND ONLY SENDING AUDIO CLIPS IF REQUESTED BY SERVER?

ACTUALLY, SET KEEPALIVE FOR 1 DAY AND ONLY SEND DEVICE INFO UPDATES WITH QOS=1 UPON SIGNIFICANT CHANGE (CHECK EVERY 5 MINUTES)

# CHECK SECTION 7.2.1 OF https://content.u-blox.com/sites/default/files/documents/LENA-R8-Application-Development_AppNote_UBX-22038374.pdf TO SEE IF WE NEED TO VERIFY NETWORK CONNECTIVITY DIRECTLY (USING INITIAL BEARER)

# CHECK SECTION 8.2 OF https://content.u-blox.com/sites/default/files/documents/LENA-R8-Application-Development_AppNote_UBX-22038374.pdf FOR HOW TO HANDLE ALL UNEXPECTED CONDITIONS (MAKE THIS AN FSM)

# DO ALL OF THIS ONLY ONE TIME WHEN INITIALLY PROVISIONING EACH DEVICE (ONLY IF NOT USING THINGSTREAM BUT TALKING TO AWS IOT CORE DIRECTLY)

# Store AWS certificate onto device (CA, CC, and PK)
# For each of the following commands, there will be a ">" response, after which you have to copy-paste the entire file contents and press ENTER, will respond with "OK"
AT+UDWNFILE="aws_ca.pem",1188
AT+UDWNFILE="383847e4d4-certificate.pem.crt",1224
AT+UDWNFILE="383847e4d4-private.pem.key",1679

# Verify availability of all modules on-device
# Each command will respond with "+ULSTFILE: <num> OK"
AT+ULSTFILE=2,"aws_ca.pem"
AT+ULSTFILE=2,"383847e4d4-certificate.pem.crt"
AT+ULSTFILE=2,"383847e4d4-private.pem.key"

# Import everything into the on-device Certificates Manager
# Each command will respond with "+USECMNG: <string> OK"
AT+USECMNG=1,0,"AWS_CA","aws_ca.pem"
AT+USECMNG=1,1,"AWS_Client","383847e4d4-certificate.pem.crt"
AT+USECMNG=1,2,"Client_Key","383847e4d4-private.pem.key"

# Configure the security profile
# Each command will respond with "OK"
AT+USECPRF=0
AT+USECPRF=0,0,1
AT+USECPRF=0,2,0
AT+USECPRF=0,3,"AWS_CA"
AT+USECPRF=0,5,"AWS_Client"
AT+USECPRF=0,6,"Client_Key"
AT+USECPRF=0,10,"xxx-ats.iot.us-east-2.amazonaws.com" (MIGHT NOT NEED THIS, DON'T USE IF NOT NECESSARY)

# AT DEVICE BOOT TIME
# Should always respond with something ending with "OK"
AT+UMQTT=2,"xxx-ats.iot.us-east2.amazonaws.com",8883				# Set remote server name (use correct endpoint here)
AT+UMQTT=11,1,0 													# Use secure connections
AT+UMQTTC=1 														# Connect to AWS broker and start secure MQTT session
AT+UMQTTC=4,0,"building/groundfloor/office_1/heating" 				# Subscribe to some topic
AT+UMQTTC=2,0,0,0,"building/groundfloor/office_1/temperature","10degrees Celsius" 		# Publish message to some topic
Upon receipt of message, will receive "+UUMQTTC: 6,1", read the message with: AT+UMQTTC=6,1

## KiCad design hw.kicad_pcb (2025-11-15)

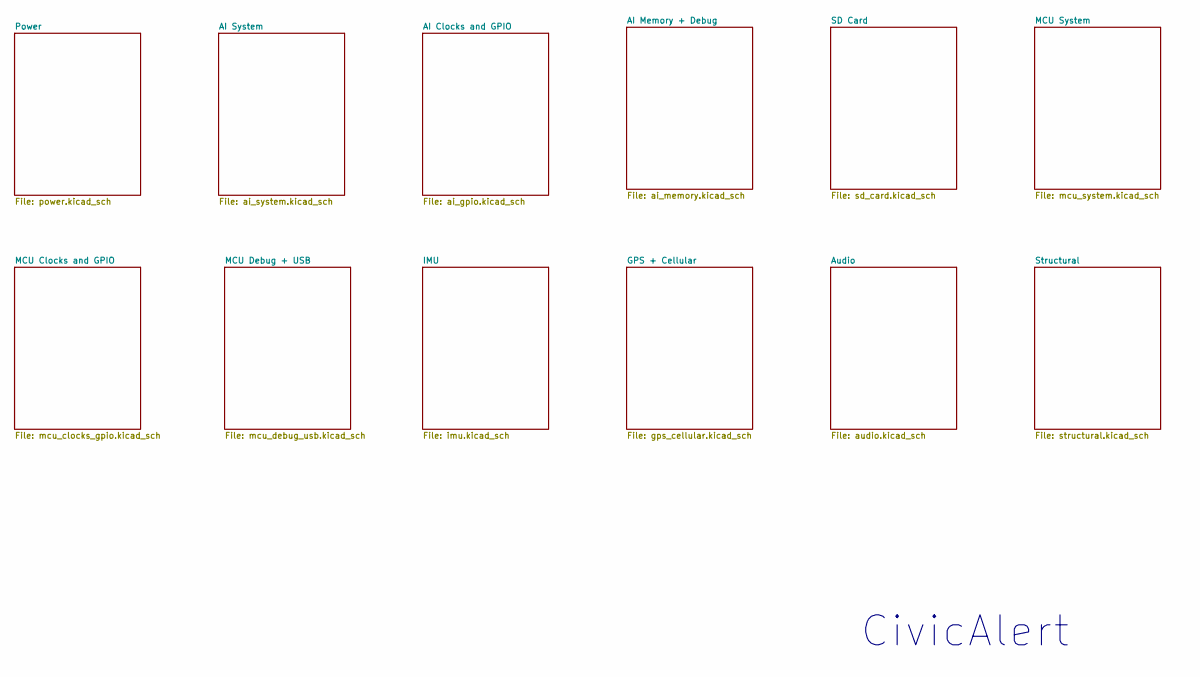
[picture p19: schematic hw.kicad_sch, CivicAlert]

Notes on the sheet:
CivicAlert

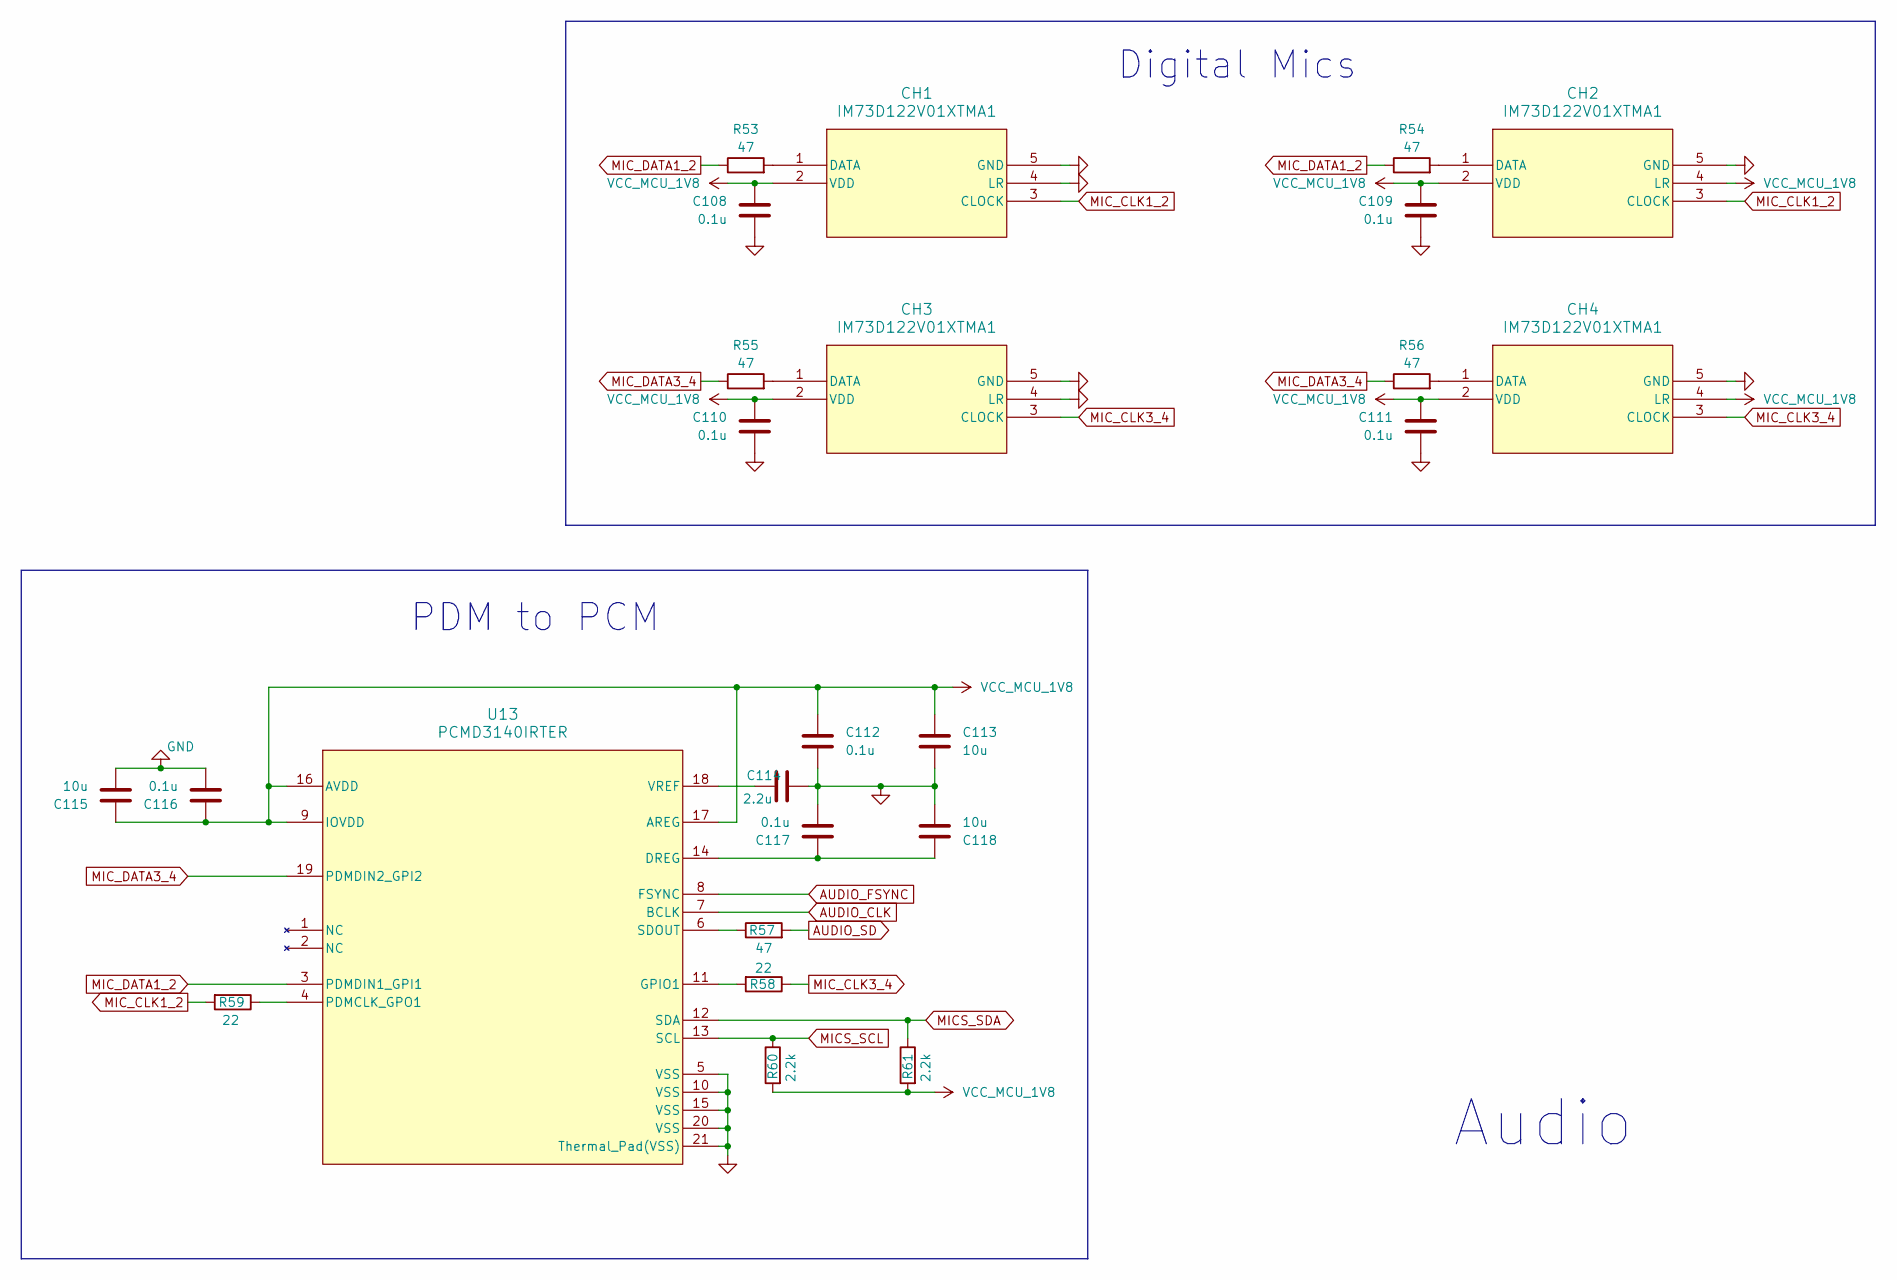
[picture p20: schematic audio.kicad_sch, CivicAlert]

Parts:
C108, C109, C110, C111, C112, C116, C117: 0.1u; C_0402_1005Metric; MPN GRM155R71C104KA88J
C113, C115, C118: 10u; C_0603_1608Metric; MPN GRM188Z71A106KA73D
C114: 2.2u; C_0402_1005Metric; MPN GRT155C71A225KE13D
CH1, CH2, CH3, CH4: IM73D122V01XTMA1; MPN IM73D122V01XTMA1
R53, R54, R55, R56, R57: 47; R_0402_1005Metric
R58, R59: 22; R_0402_1005Metric
R60, R61: 2.2k; R_0402_1005Metric
U13: PCMD3140IRTER; MPN PCMD3140IRTER

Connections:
AUDIO_CLK: U13.7 (BCLK); also elsewhere on the board
AUDIO_FSYNC: U13.8 (FSYNC); also elsewhere on the board
AUDIO_SD: R57.2; also elsewhere on the board
GND: C108.2, C109.2, C110.2, C111.2, C112.2, C113.2, C114.2, C115.2, C116.2, C117.2, C118.2, CH1.4 (LR), CH1.5 (GND), CH2.5 (GND), CH3.4 (LR), CH3.5 (GND), CH4.5 (GND), U13.5 (VSS), U13.10 (VSS), U13.15 (VSS), U13.20 (VSS), U13.21 (Thermal_Pad(VSS)); also elsewhere on the board
MICS_SCL: R60.1, U13.13 (SCL); also elsewhere on the board
MICS_SDA: R61.1, U13.12 (SDA); also elsewhere on the board
MIC_CLK1_2: CH1.3 (CLOCK), CH2.3 (CLOCK), R59.2
MIC_CLK3_4: CH3.3 (CLOCK), CH4.3 (CLOCK), R58.1
MIC_DATA1_2: R53.1, R54.1, U13.3 (PDMDIN1_GPI1)
MIC_DATA3_4: R55.1, R56.1, U13.19 (PDMDIN2_GPI2)
unnamed: CH1.1 (DATA), R53.2
unnamed: CH2.1 (DATA), R54.2
unnamed: CH3.1 (DATA), R55.2
unnamed: CH4.1 (DATA), R56.2
unnamed: C117.1, C118.1, U13.14 (DREG)
unnamed: R58.2, U13.11 (GPIO1)
unnamed: R59.1, U13.4 (PDMCLK_GPO1)
unnamed: R57.1, U13.6 (SDOUT)
unnamed: C114.1, U13.18 (VREF)
VCC_MCU_1V8: C108.1, C109.1, C110.1, C111.1, C112.1, C113.1, C115.1, C116.1, CH1.2 (VDD), CH2.2 (VDD), CH2.4 (LR), CH3.2 (VDD), CH4.2 (VDD), CH4.4 (LR), R60.2, R61.2, U13.9 (IOVDD), U13.16 (AVDD), U13.17 (AREG); also elsewhere on the board

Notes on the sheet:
Digital Mics
PDM to PCM
Audio

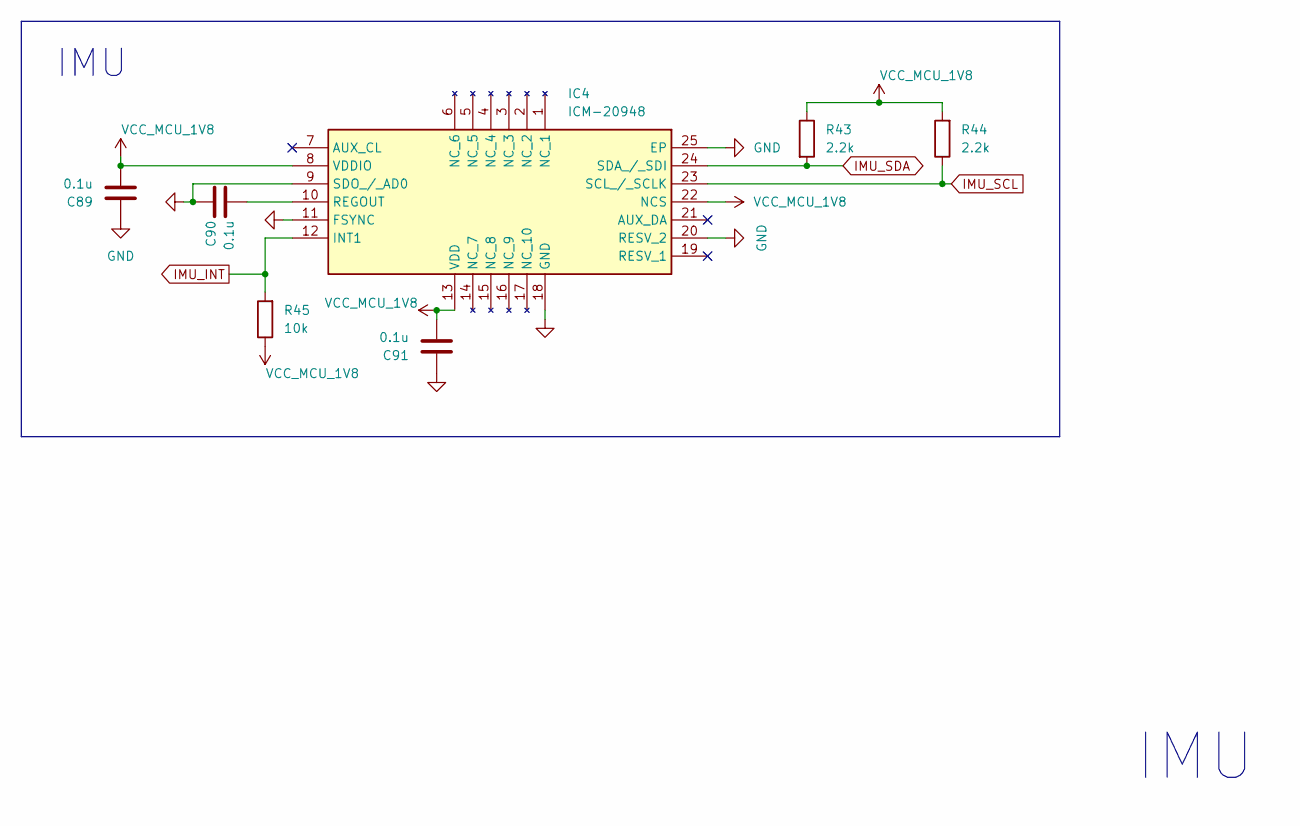
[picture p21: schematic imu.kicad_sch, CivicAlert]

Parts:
C89, C90, C91: 0.1u; C_0402_1005Metric; MPN GRM155R71C104KA88J
IC4: ICM-20948; MPN ICM-20948
R43, R44: 2.2k; R_0402_1005Metric
R45: 10k; R_0402_1005Metric

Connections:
GND: C89.1, C90.1, C91.1, IC4.9 (SDO_/_AD0), IC4.11 (FSYNC), IC4.18 (GND), IC4.20 (RESV_2), IC4.25 (EP); also elsewhere on the board
IMU_INT: IC4.12 (INT1), R45.2; also elsewhere on the board
IMU_SCL: IC4.23 (SCL_/_SCLK), R44.1; also elsewhere on the board
IMU_SDA: IC4.24 (SDA_/_SDI), R43.2; also elsewhere on the board
unnamed: C90.2, IC4.10 (REGOUT)
VCC_MCU_1V8: C89.2, C91.2, IC4.8 (VDDIO), IC4.13 (VDD), IC4.22 (NCS), R43.1, R44.2, R45.1; also elsewhere on the board

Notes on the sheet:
IMU

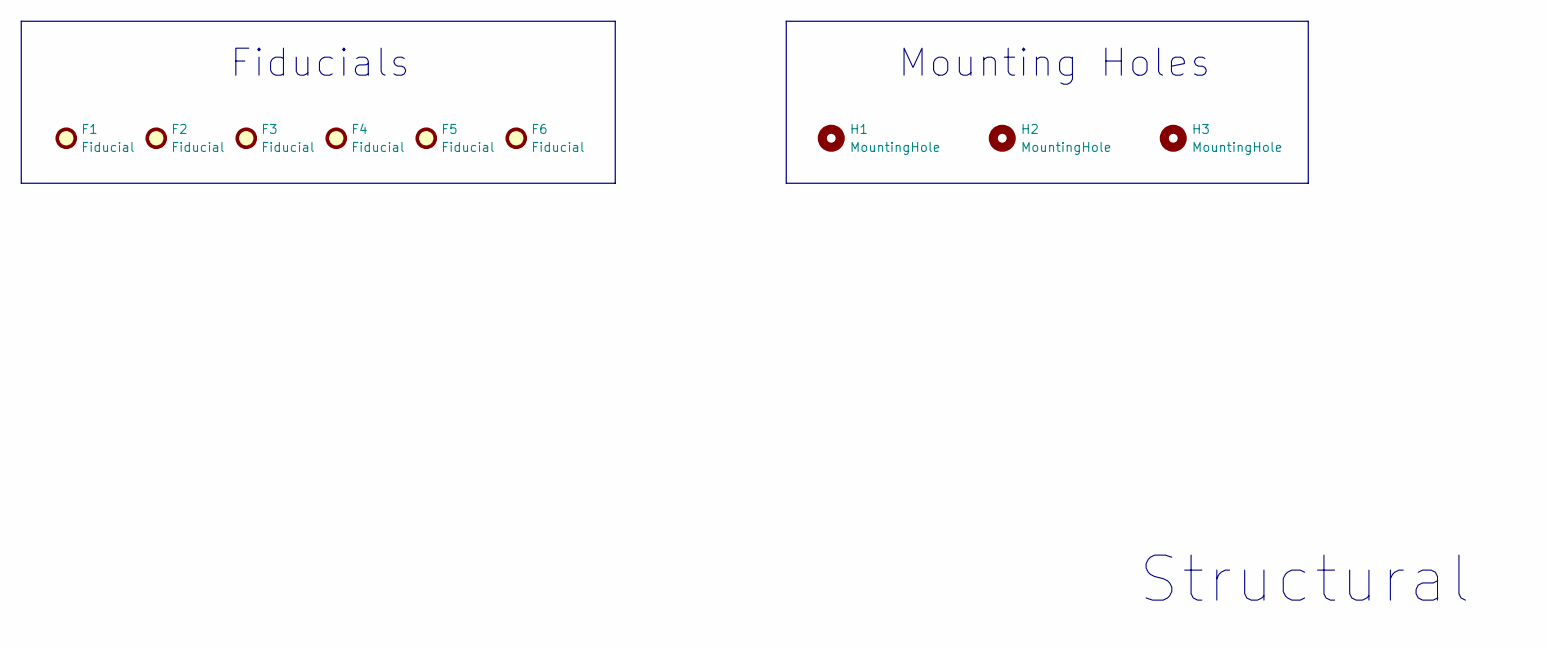
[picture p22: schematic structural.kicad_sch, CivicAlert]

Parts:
F1, F2, F3, F4, F5, F6: Fiducial; Fiducial_1mm_Mask3mm
H1, H2, H3: MountingHole; MountingHole_2.2mm_M2

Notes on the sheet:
Structural
Mounting Holes
Fiducials

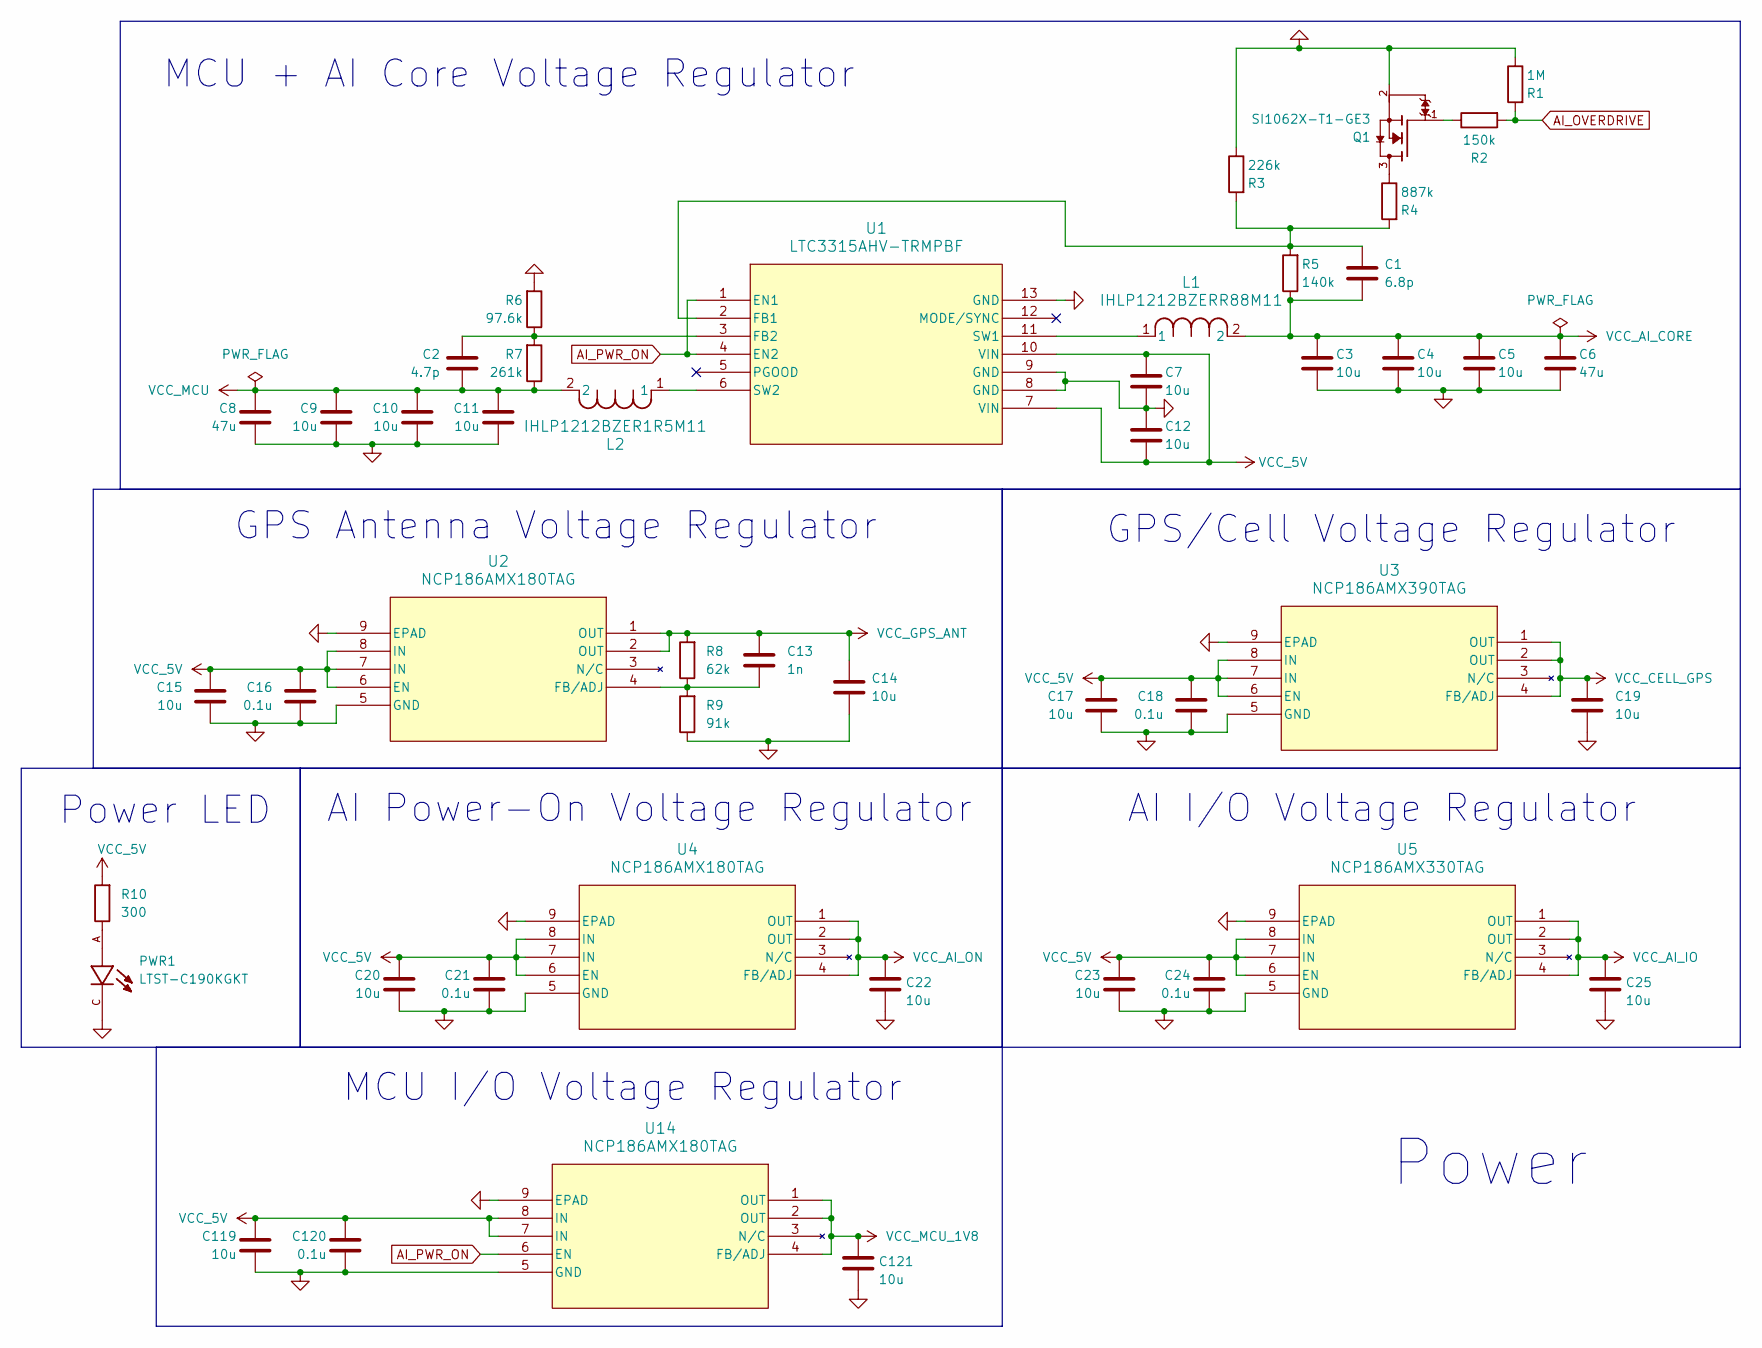
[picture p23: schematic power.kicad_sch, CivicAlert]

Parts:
C1: 6.8p; C_0402_1005Metric; MPN GCM1555C1H6R8BA16J
C2: 4.7p; C_0402_1005Metric; MPN GCM1555C1H4R7CA16D
C3, C4, C5, C7, C9, C10, C11, C12: 10u; C_0805_2012Metric; MPN CGA4J1X7R0J106M125AC
C6, C8: 47u; C_1206_3216Metric; MPN C3216X7S0J476M160AC
C13: 1n; C_0402_1005Metric; MPN GRM155R71H102JA01J
C14, C15, C17, C19, C20, C22, C23, C25, C119, C121: 10u; C_0603_1608Metric; MPN GRM188Z71A106KA73D
C16, C18, C21, C24, C120: 0.1u; C_0402_1005Metric; MPN GRM155R71C104KA88J
L1: IHLP1212BZERR88M11; MPN IHLP1212BZERR88M11
L2: IHLP1212BZER1R5M11; MPN IHLP1212BZER1R5M11
PWR1: LTST-C190KGKT; MPN LTST-C190KGKT
Q1: SI1062X-T1-GE3; MPN SI1062X-T1-GE3
R1: 1M; R_0402_1005Metric
R2: 150k; R_0402_1005Metric
R3: 226k; R_0603_1608Metric; MPN RT0603BRD07226KL
R4: 887k; R_0603_1608Metric; MPN RT0603BRD07887KL
R5: 140k; R_0603_1608Metric; MPN RT0603BRD07140KL
R6: 97.6k; R_0603_1608Metric; MPN RT0603BRD0797K6L
R7: 261k; R_0603_1608Metric; MPN RT0603BRD07261KL
R8: 62k; R_0402_1005Metric
R9: 91k; R_0402_1005Metric
R10: 300; R_0402_1005Metric
U1: LTC3315AHV-TRMPBF; LTC3315AHV; MPN LTC3315AHV-TRMPBF
U2, U4, U14: NCP186AMX180TAG; NCP186AMX; MPN NCP186AMX180TAG
U3: NCP186AMX390TAG; NCP186AMX; MPN NCP186AMX390TAG
U5: NCP186AMX330TAG; NCP186AMX; MPN NCP186AMX330TAG

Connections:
AI_OVERDRIVE: R1.2, R2.2; also elsewhere on the board
AI_PWR_ON: U1.1 (EN1), U1.4 (EN2), U14.6 (EN); also elsewhere on the board
GND: C3.2, C4.2, C5.2, C6.2, C7.2, C8.2, C9.2, C10.2, C11.2, C12.1, C14.2, C15.2, C16.2, C17.2, C18.2, C19.2, C20.2, C21.2, C22.2, C23.2, C24.2, C25.2, C119.2, C120.2, C121.2, PWR1.C, Q1.2, R1.1, R3.1, R6.2, R9.1, U1.8 (GND), U1.9 (GND), U1.13 (GND), U2.5 (GND), U2.9 (EPAD), U3.5 (GND), U3.9 (EPAD), U4.5 (GND), U4.9 (EPAD), U5.5 (GND), U5.9 (EPAD), U14.5 (GND), U14.9 (EPAD); also elsewhere on the board
unnamed: PWR1.A, R10.1
unnamed: Q1.1, R2.1
unnamed: Q1.3, R4.1
unnamed: C1.1, R3.2, R4.2, R5.2, U1.2 (FB1)
unnamed: C2.1, R6.1, R7.2, U1.3 (FB2)
unnamed: L1.1, U1.11 (SW1)
unnamed: L2.1, U1.6 (SW2)
unnamed: C13.2, R8.1, R9.2, U2.4 (FB/ADJ)
VCC_5V: C7.1, C12.2, C15.1, C16.1, C17.1, C18.1, C20.1, C21.1, C23.1, C24.1, C119.1, C120.1, R10.2, U1.7 (VIN), U1.10 (VIN), U2.6 (EN), U2.7 (IN), U2.8 (IN), U3.6 (EN), U3.7 (IN), U3.8 (IN), U4.6 (EN), U4.7 (IN), U4.8 (IN), U5.6 (EN), U5.7 (IN), U5.8 (IN), U14.7 (IN), U14.8 (IN); also elsewhere on the board
VCC_AI_CORE: C1.2, C3.1, C4.1, C5.1, C6.1, L1.2, R5.1; also elsewhere on the board
VCC_AI_IO: C25.1, U5.1 (OUT), U5.2 (OUT), U5.4 (FB/ADJ); also elsewhere on the board
VCC_AI_ON: C22.1, U4.1 (OUT), U4.2 (OUT), U4.4 (FB/ADJ); also elsewhere on the board
VCC_CELL_GPS: C19.1, U3.1 (OUT), U3.2 (OUT), U3.4 (FB/ADJ); also elsewhere on the board
VCC_GPS_ANT: C13.1, C14.1, R8.2, U2.1 (OUT), U2.2 (OUT); also elsewhere on the board
VCC_MCU: C2.2, C8.1, C9.1, C10.1, C11.1, L2.2, R7.1; also elsewhere on the board
VCC_MCU_1V8: C121.1, U14.1 (OUT), U14.2 (OUT), U14.4 (FB/ADJ); also elsewhere on the board

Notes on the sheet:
GPS/Cell Voltage Regulator
AI I/O Voltage Regulator
Power LED
MCU + AI Core Voltage Regulator
GPS Antenna Voltage Regulator
AI Power-On Voltage Regulator
MCU I/O Voltage Regulator
Power

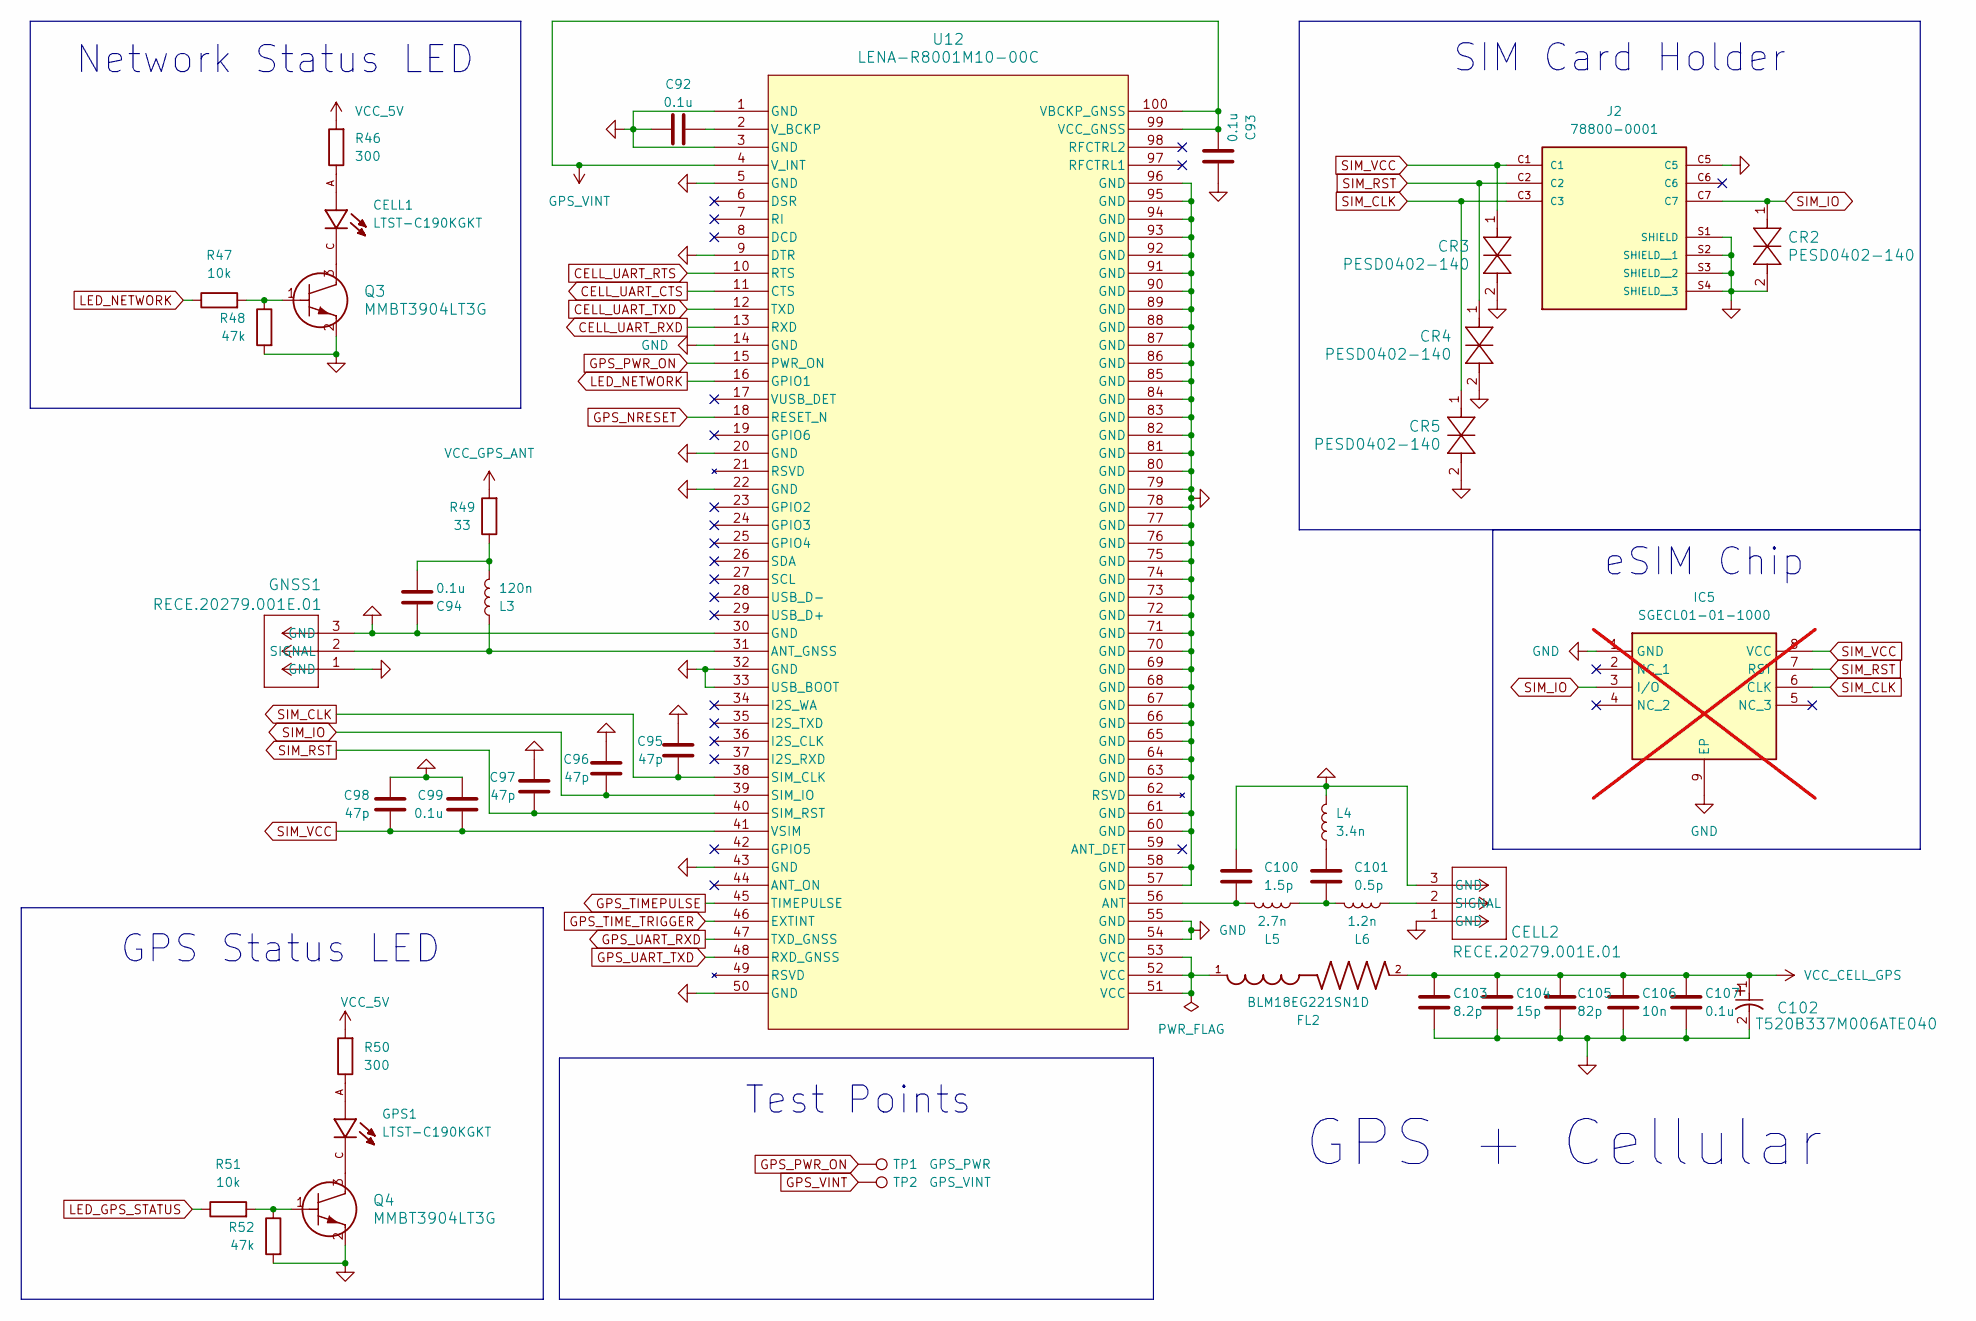
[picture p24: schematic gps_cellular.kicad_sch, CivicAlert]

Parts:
C92, C93, C94, C99, C107: 0.1u; C_0402_1005Metric; MPN GRM155R71C104KA88J
C95, C96, C97, C98: 47p; C_0402_1005Metric; MPN GRT1555C1H470JA02J
C100: 1.5p; C_0402_1005Metric; MPN GRT1555C1H1R5CA02J
C101: 0.5p; C_0402_1005Metric; MPN GJM1555C1HR50WB01D
C102: T520B337M006ATE040; MPN T520B337M006ATE040
C103: 8.2p; C_0402_1005Metric; MPN GRM1555C1E8R2CA01D
C104: 15p; C_0402_1005Metric; MPN GRT1555C1H150JA02J
C105: 82p; C_0402_1005Metric; MPN GRT1555C1H820FA02D
C106: 10n; C_0402_1005Metric; MPN GCM155R71H103KA55D
CELL1: LTST-C190KGKT; MPN LTST-C190KGKT
CELL2: RECE.20279.001E.01; MPN RECE.20279.001E.01
CR2, CR3, CR4, CR5: PESD0402-140; PESD0402-140_LTF; MPN PESD0402-140
FL2: BLM18EG221SN1D; MPN BLM18EG221SN1D
GNSS1: RECE.20279.001E.01; MPN RECE.20279.001E.01
GPS1: LTST-C190KGKT; MPN LTST-C190KGKT
IC5: SGECL01-01-1000; not fitted
J2: 78800-0001; 0788000001; MPN 0788000001
L3: 120n; L_0402_1005Metric; MPN LQW15ANR12J00
L4: 3.4n; L_0402_1005Metric; MPN LQG15WZ3N4S02D
L5: 2.7n; L_0402_1005Metric; MPN LQG15HS2N7B02D
L6: 1.2n; L_0402_1005Metric; MPN LQG15HS1N2B02D
Q3, Q4: MMBT3904LT3G; MPN BC847CE6327HTSA1
R46, R50: 300; R_0402_1005Metric
R47, R51: 10k; R_0402_1005Metric
R48, R52: 47k; R_0402_1005Metric
R49: 33; R_0402_1005Metric
TP1: GPS_PWR; TestPoint_THTPad_D1.0mm_Drill0.5mm
TP2: GPS_VINT; TestPoint_THTPad_D1.0mm_Drill0.5mm
U12: LENA-R8001M10-00C; MPN LENA-R8001M10-00C

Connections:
CELL_UART_CTS: U12.11 (CTS); also elsewhere on the board
CELL_UART_RTS: U12.10 (RTS); also elsewhere on the board
CELL_UART_RXD: U12.13 (RXD); also elsewhere on the board
CELL_UART_TXD: U12.12 (TXD); also elsewhere on the board
GND: C92.2, C93.2, C94.1, C95.1, C96.1, C97.1, C98.1, C99.1, C100.1, C102.2, C103.2, C104.2, C105.2, C106.2, C107.2, CELL2.1 (GND), CELL2.3 (GND), CR2.2, CR3.2, CR4.2, CR5.2, GNSS1.1 (GND), GNSS1.3 (GND), IC5.1 (GND), IC5.9 (EP), J2.C5, J2.S1 (SHIELD), J2.S2 (SHIELD__1), J2.S3 (SHIELD__2), J2.S4 (SHIELD__3), L4.2, Q3.2, Q4.2, R48.2, R52.2, U12.1 (GND), U12.3 (GND), U12.5 (GND), U12.9 (DTR), U12.14 (GND), U12.20 (GND), U12.22 (GND), U12.30 (GND), U12.32 (GND), U12.33 (USB_BOOT), U12.43 (GND), U12.50 (GND), U12.54 (GND), U12.55 (GND), U12.57 (GND), U12.58 (GND), U12.60 (GND), U12.61 (GND), U12.63 (GND), U12.64 (GND), U12.65 (GND), U12.66 (GND), U12.67 (GND), U12.68 (GND), U12.69 (GND), U12.70 (GND), U12.71 (GND), U12.72 (GND), U12.73 (GND), U12.74 (GND), U12.75 (GND), U12.76 (GND), U12.77 (GND), U12.78 (GND), U12.79 (GND), U12.80 (GND), U12.81 (GND), U12.82 (GND), U12.83 (GND), U12.84 (GND), U12.85 (GND), U12.86 (GND), U12.87 (GND), U12.88 (GND), U12.89 (GND), U12.90 (GND), U12.91 (GND), U12.92 (GND), U12.93 (GND), U12.94 (GND), U12.95 (GND), U12.96 (GND); also elsewhere on the board
GPS_NRESET: U12.18 (RESET_N); also elsewhere on the board
GPS_PWR_ON: TP1.1, U12.15 (PWR_ON); also elsewhere on the board
GPS_TIMEPULSE: U12.45 (TIMEPULSE); also elsewhere on the board
GPS_TIME_TRIGGER: U12.46 (EXTINT); also elsewhere on the board
GPS_UART_RXD: U12.47 (TXD_GNSS); also elsewhere on the board
GPS_UART_TXD: U12.48 (RXD_GNSS); also elsewhere on the board
GPS_VINT: C93.1, TP2.1, U12.4 (V_INT), U12.99 (VCC_GNSS), U12.100 (VBCKP_GNSS)
LED_GPS_STATUS: R51.1; also elsewhere on the board
LED_NETWORK: R47.1, U12.16 (GPIO1)
unnamed: C94.2, L3.2, R49.1
unnamed: C101.1, L4.1
unnamed: C101.2, L5.2, L6.1
unnamed: CELL1.A, R46.1
unnamed: CELL1.C, Q3.3
unnamed: CELL2.2 (SIGNAL), L6.2
unnamed: FL2.1, U12.51 (VCC), U12.52 (VCC), U12.53 (VCC)
unnamed: GNSS1.2 (SIGNAL), L3.1, U12.31 (ANT_GNSS)
unnamed: GPS1.A, R50.1
unnamed: GPS1.C, Q4.3
unnamed: Q3.1, R47.2, R48.1
unnamed: Q4.1, R51.2, R52.1
unnamed: C100.2, L5.1, U12.56 (ANT)
unnamed: C92.1, U12.2 (V_BCKP)
SIM_CLK: C95.2, CR5.1, IC5.6 (CLK), J2.C3, U12.38 (SIM_CLK)
SIM_IO: C96.2, CR2.1, IC5.3 (I/O), J2.C7, U12.39 (SIM_IO)
SIM_RST: C97.2, CR4.1, IC5.7 (RST), J2.C2, U12.40 (SIM_RST)
SIM_VCC: C98.2, C99.2, CR3.1, IC5.8 (VCC), J2.C1, U12.41 (VSIM)
VCC_5V: R46.2, R50.2; also elsewhere on the board
VCC_CELL_GPS: C102.1, C103.1, C104.1, C105.1, C106.1, C107.1, FL2.2; also elsewhere on the board
VCC_GPS_ANT: R49.2; also elsewhere on the board

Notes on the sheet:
GPS Status LED
Test Points
Network Status LED
GPS + Cellular
SIM Card Holder
eSIM Chip

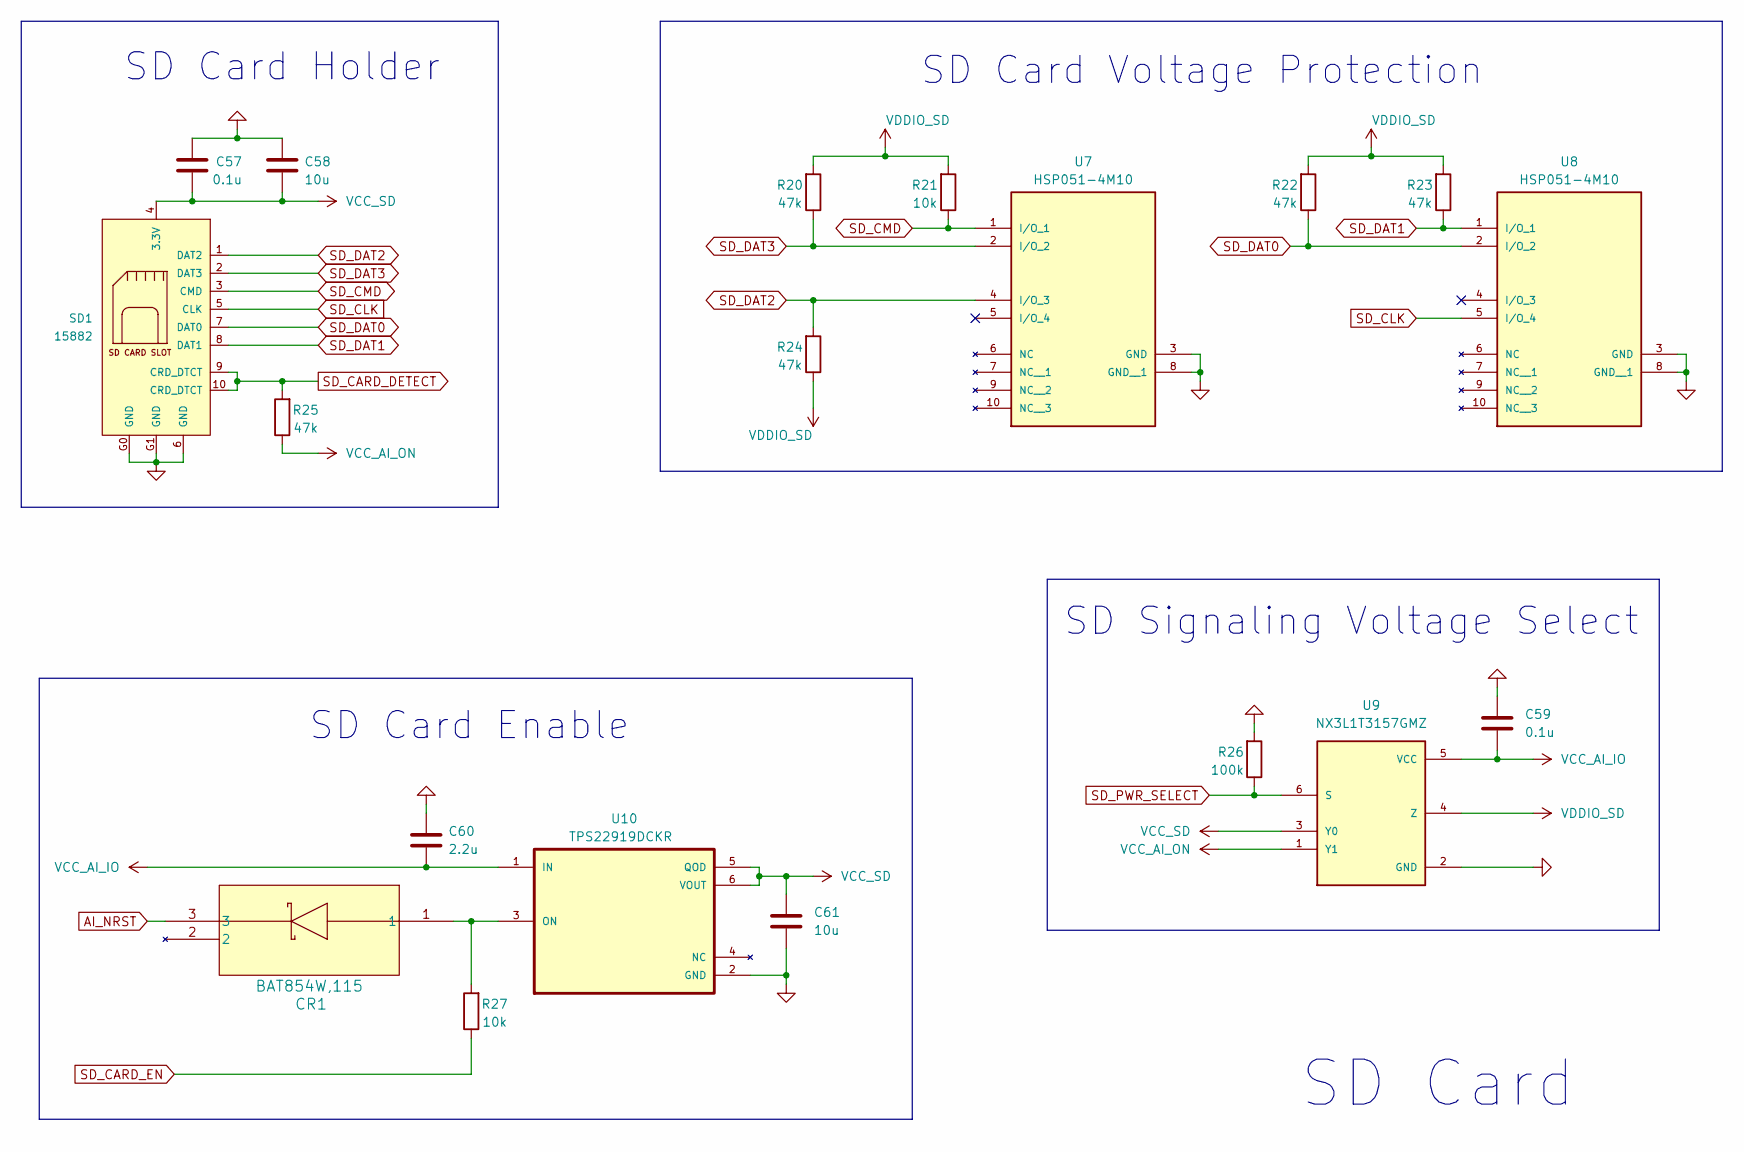
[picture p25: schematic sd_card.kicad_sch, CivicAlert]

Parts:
C57, C59: 0.1u; C_0402_1005Metric; MPN GRM155R71C104KA88J
C58, C61: 10u; C_0603_1608Metric; MPN GRM188Z71A106KA73D
C60: 2.2u; C_0402_1005Metric; MPN GRT155C71A225KE13D
CR1: BAT854W,115; BAT854AW,115; MPN BAT854W,115
R20, R22, R23, R24, R25: 47k; R_0402_1005Metric
R21, R27: 10k; R_0402_1005Metric
R26: 100k; R_0402_1005Metric
SD1: 15882; MPN 15882
U7, U8: HSP051-4M10; MPN HSP051-4M10
U9: NX3L1T3157GMZ; MPN NX3L1T3157GMZ
U10: TPS22919DCKR; MPN TPS22919DCKR

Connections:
AI_NRST: CR1.3; also elsewhere on the board
GND: C57.1, C58.1, C59.1, C60.1, C61.2, R26.2, SD1.6 (GND), SD1.G0 (GND), SD1.G1 (GND), U7.3 (GND), U7.8 (GND__1), U8.3 (GND), U8.8 (GND__1), U9.2 (GND), U10.2 (GND); also elsewhere on the board
unnamed: CR1.1, R27.2, U10.3 (ON)
SD_CARD_DETECT: R25.2, SD1.9 (CRD_DTCT), SD1.10 (CRD_DTCT); also elsewhere on the board
SD_CARD_EN: R27.1; also elsewhere on the board
SD_CLK: SD1.5 (CLK), U8.5 (I/O_4); also elsewhere on the board
SD_CMD: R21.1, SD1.3 (CMD), U7.1 (I/O_1); also elsewhere on the board
SD_DAT0: R22.1, SD1.7 (DAT0), U8.2 (I/O_2); also elsewhere on the board
SD_DAT1: R23.1, SD1.8 (DAT1), U8.1 (I/O_1); also elsewhere on the board
SD_DAT2: R24.2, SD1.1 (DAT2), U7.4 (I/O_3); also elsewhere on the board
SD_DAT3: R20.1, SD1.2 (DAT3), U7.2 (I/O_2); also elsewhere on the board
SD_PWR_SELECT: R26.1, U9.6 (S); also elsewhere on the board
VCC_AI_IO: C59.2, C60.2, U9.5 (VCC), U10.1 (IN); also elsewhere on the board
VCC_AI_ON: R25.1, U9.1 (Y1); also elsewhere on the board
VCC_SD: C57.2, C58.2, C61.1, SD1.4 (3.3V), U9.3 (Y0), U10.5 (QOD), U10.6 (VOUT)
VDDIO_SD: R20.2, R21.2, R22.2, R23.2, R24.1, U9.4 (Z); also elsewhere on the board

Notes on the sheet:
SD Card Voltage Protection
SD Card
SD Card Enable
SD Signaling Voltage Select
SD Card Holder

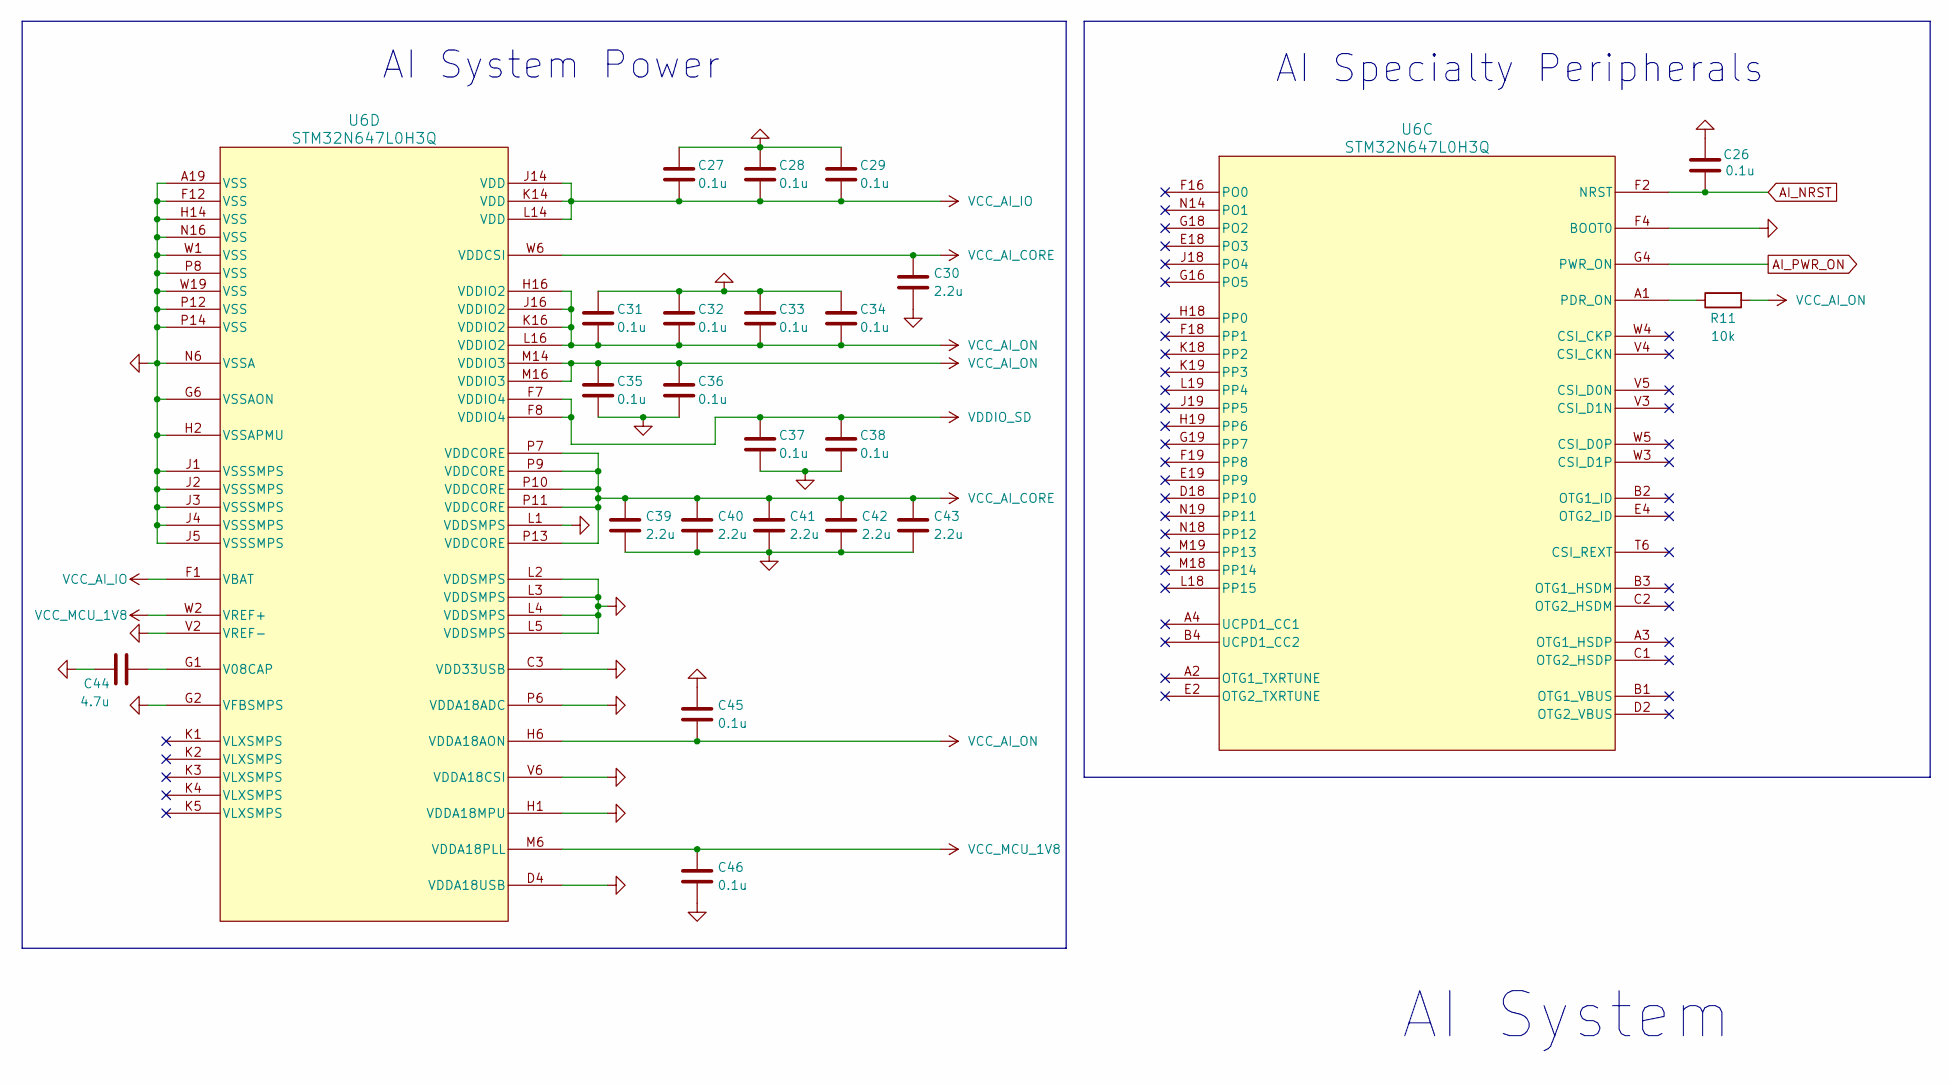
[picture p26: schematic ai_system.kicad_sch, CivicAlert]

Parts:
C26, C27, C28, C29, C31, C32, C33, C34, C35, C36, C37, C38, C45, C46: 0.1u; C_0201_0603Metric; MPN GRM033Z71C104KE14D
C30, C39, C40, C41, C42, C43: 2.2u; C_0201_0603Metric; MPN GRT033D70J105ME13D
C44: 4.7u; C_0402_1005Metric; MPN GRT155D70J475ME13D
R11: 10k; R_0402_1005Metric
U6: STM32N647L0H3Q; MPN STM32N647L0H3Q

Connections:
AI_NRST: C26.1, U6.F2 (NRST); also elsewhere on the board
AI_PWR_ON: U6.G4 (PWR_ON); also elsewhere on the board
GND: C26.2, C27.1, C28.1, C29.1, C30.2, C31.1, C32.1, C33.1, C34.1, C35.2, C36.2, C37.2, C38.2, C39.2, C40.2, C41.2, C42.2, C43.2, C44.2, C45.1, C46.2, U6.A19 (VSS), U6.C3 (VDD33USB), U6.D4 (VDDA18USB), U6.F4 (BOOT0), U6.F12 (VSS), U6.G2 (VFBSMPS), U6.G6 (VSSAON), U6.H1 (VDDA18MPU), U6.H2 (VSSAPMU), U6.H14 (VSS), U6.J1 (VSSSMPS), U6.J2 (VSSSMPS), U6.J3 (VSSSMPS), U6.J4 (VSSSMPS), U6.J5 (VSSSMPS), U6.L1 (VDDSMPS), U6.L2 (VDDSMPS), U6.L3 (VDDSMPS), U6.L4 (VDDSMPS), U6.L5 (VDDSMPS), U6.N6 (VSSA), U6.N16 (VSS), U6.P6 (VDDA18ADC), U6.P8 (VSS), U6.P12 (VSS), U6.P14 (VSS), U6.V2 (VREF-), U6.V6 (VDDA18CSI), U6.W1 (VSS), U6.W19 (VSS); also elsewhere on the board
unnamed: R11.1, U6.A1 (PDR_ON)
unnamed: C44.1, U6.G1 (V08CAP)
VCC_AI_CORE: C30.1, C39.1, C40.1, C41.1, C42.1, C43.1, U6.P7 (VDDCORE), U6.P9 (VDDCORE), U6.P10 (VDDCORE), U6.P11 (VDDCORE), U6.P13 (VDDCORE), U6.W6 (VDDCSI); also elsewhere on the board
VCC_AI_IO: C27.2, C28.2, C29.2, U6.F1 (VBAT), U6.J14 (VDD), U6.K14 (VDD), U6.L14 (VDD); also elsewhere on the board
VCC_AI_ON: C31.2, C32.2, C33.2, C34.2, C35.1, C36.1, C45.2, R11.2, U6.H6 (VDDA18AON), U6.H16 (VDDIO2), U6.J16 (VDDIO2), U6.K16 (VDDIO2), U6.L16 (VDDIO2), U6.M14 (VDDIO3), U6.M16 (VDDIO3); also elsewhere on the board
VCC_MCU_1V8: C46.1, U6.M6 (VDDA18PLL), U6.W2 (VREF+); also elsewhere on the board
VDDIO_SD: C37.1, C38.1, U6.F7 (VDDIO4), U6.F8 (VDDIO4); also elsewhere on the board

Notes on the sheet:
AI System Power
AI Specialty Peripherals
AI System

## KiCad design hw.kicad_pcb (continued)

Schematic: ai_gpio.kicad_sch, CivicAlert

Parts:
R12: 22; R_0402_1005Metric
R13, R14: 10k; R_0402_1005Metric
R63, R64: 2.2k; R_0402_1005Metric
U6: STM32N647L0H3Q; MPN STM32N647L0H3Q

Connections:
AI_BOOT_DEV: U6.T10 (PA6); also elsewhere on the board
AI_DATA_IN_CS: U6.T15 (PA15); also elsewhere on the board
AI_DATA_IN_MISO: U6.W15 (PB4); also elsewhere on the board
AI_DATA_IN_MOSI: U6.V15 (PA7); also elsewhere on the board
AI_DATA_IN_SCK: U6.V10 (PA5); also elsewhere on the board
AI_DATA_OUT_SCL: R64.1, U6.T9 (PA8); also elsewhere on the board
AI_DATA_OUT_SDA: R63.1, U6.V9 (PA9); also elsewhere on the board
AI_HOST_WAKEUP: U6.W12 (PA1); also elsewhere on the board
AI_OVERDRIVE: U6.V1 (PF13); also elsewhere on the board
AI_SWCLK: U6.V7 (PA14); also elsewhere on the board
AI_SWDIO: R12.1; also elsewhere on the board
FLASH_CLK: U6.U19 (PN6); also elsewhere on the board
FLASH_DQS: U6.R19 (PN0); also elsewhere on the board
FLASH_IO0: U6.T19 (PN2); also elsewhere on the board
FLASH_IO1: U6.P19 (PN3); also elsewhere on the board
FLASH_IO2: U6.V19 (PN4); also elsewhere on the board
FLASH_IO3: U6.U18 (PN5); also elsewhere on the board
FLASH_IO4: U6.V18 (PN8); also elsewhere on the board
FLASH_IO5: U6.T18 (PN9); also elsewhere on the board
FLASH_IO6: U6.R18 (PN10); also elsewhere on the board
FLASH_IO7: U6.P18 (PN11); also elsewhere on the board
FLASH_NCS: U6.P16 (PN1); also elsewhere on the board
GND: R13.1, R14.1; also elsewhere on the board
unnamed: R12.2, U6.W7 (PA13)
unnamed: R14.2, U6.E1 (PC14-OSC32_IN)
unnamed: R13.2, U6.A5 (PH0-OSC_IN)
SD_CARD_DETECT: U6.W18 (PN12); also elsewhere on the board
SD_CARD_EN: U6.B19 (PE2); also elsewhere on the board
SD_CLK: U6.A6 (PC12); also elsewhere on the board
SD_CMD: U6.D7 (PH2); also elsewhere on the board
SD_DAT0: U6.F6 (PC8); also elsewhere on the board
SD_DAT1: U6.D5 (PC9); also elsewhere on the board
SD_DAT2: U6.D6 (PC10); also elsewhere on the board
SD_DAT3: U6.B6 (PC11); also elsewhere on the board
SD_PWR_SELECT: U6.A18 (PE0); also elsewhere on the board
VCC_MCU_1V8: R63.2, R64.2; also elsewhere on the board

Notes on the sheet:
AI Clocks and GPIO
AI GPIO Banks A-D
AI GPIO Banks E-N

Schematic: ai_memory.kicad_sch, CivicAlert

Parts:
B1: 009159010061911
BOOT1: PTS810; MPN PTS810
C51, C54, C55: 0.1u; C_0402_1005Metric; MPN GRM155R71C104KA88J
C52, C53, C56: 4.7u; C_0402_1005Metric; MPN GRT155D70J475ME13D
CR6: BAT854W,115; BAT854AW,115; MPN BAT854W,115
IC1: MX25UM25645GXDI00-T; MX25UM25645GXDI00; MPN MX25UM25645GXDI00-T
IC2: ESDALC6V1W5; MPN ESDALC6V1W5
R15, R16, R17, R62: 10k; R_0402_1005Metric
R18, R19: 22; R_0402_1005Metric

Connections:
AI_BOOT_DEV: BOOT1.1, BOOT1.2, R62.2; also elsewhere on the board
AI_NRST: B1.9 (NRST), CR6.3, IC2.5 (I/04); also elsewhere on the board
AI_SWCLK: IC2.4 (I/03), R19.1; also elsewhere on the board
AI_SWDIO: IC2.3 (I/02), R18.1; also elsewhere on the board
AI_SWO: B1.5 (JTDO/SWO), IC2.1 (I/01)
FLASH_CLK: IC1.B2 (SCLK); also elsewhere on the board
FLASH_DQS: IC1.C3 (DQS); also elsewhere on the board
FLASH_IO0: IC1.D3 (SIO0); also elsewhere on the board
FLASH_IO1: IC1.D2 (SIO1); also elsewhere on the board
FLASH_IO2: IC1.C4 (SIO2); also elsewhere on the board
FLASH_IO3: IC1.D4 (SIO3); also elsewhere on the board
FLASH_IO4: IC1.D5 (SIO4); also elsewhere on the board
FLASH_IO5: IC1.E3 (SIO5); also elsewhere on the board
FLASH_IO6: IC1.E2 (SIO6); also elsewhere on the board
FLASH_IO7: IC1.E1 (SIO7); also elsewhere on the board
FLASH_NCS: IC1.C2 (CS#), R17.2; also elsewhere on the board
GND: B1.6 (GND), C51.2, C52.2, C53.2, C54.2, C55.2, C56.2, IC1.B3 (GND), IC1.C1 (VSSQ_1), IC1.E5 (VSSQ_2), IC2.2 (GND), R62.1; also elsewhere on the board
unnamed: B1.4 (JCLK/SWCLK), R19.2
unnamed: B1.3 (JTMS/SWDIO), R18.2
unnamed: IC1.A5 (ECS#), R16.2
unnamed: CR6.1, IC1.A4 (RESET#), R15.1
VCC_AI_IO: B1.10 (VCC), BOOT1.3, BOOT1.4; also elsewhere on the board
VCC_AI_ON: C51.1, C52.1, C53.1, C54.1, C55.1, C56.1, IC1.B4 (VCC), IC1.D1 (VCCQ_1), IC1.E4 (VCCQ_2), R15.2, R16.1, R17.1; also elsewhere on the board

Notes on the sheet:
AI Memory + Debug
Flash Memory
AI JTAG/SWD Connector
Boot Mode Switch

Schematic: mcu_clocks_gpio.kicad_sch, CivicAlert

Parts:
C82: 10n; C_0402_1005Metric; MPN GCM155R71H103KA55D
C83, C85: 0.1u; C_0402_1005Metric; MPN GRM155R71C104KA88J
C84, C86: 3.3p; C_0402_1005Metric; MPN GRT1555C1H3R3CA02J
R32, R34, R38: 22; R_0402_1005Metric
R33, R35: 47; R_0402_1005Metric
R36, R37: 10k; R_0402_1005Metric
U11: STM32H745ZIT6; MPN STM32H745ZIT6
Y3: ATX-H11-F-25.000MHz-F25-T; ATX-H11-F-25_000MHz-F25-T; MPN ATX-H11-F-25.000MHz-F25-T
Y4: ABS07AIG-32.768KHZ-7-T; ABS07AIG_32_768KHZ_7_T; MPN ABS07AIG-32.768KHZ-7-T

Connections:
AI_DATA_IN_CS: U11.72 (PB12); also elsewhere on the board
AI_DATA_IN_MISO: U11.74 (PB14); also elsewhere on the board
AI_DATA_IN_MOSI: U11.75 (PB15); also elsewhere on the board
AI_DATA_IN_SCK: U11.73 (PB13); also elsewhere on the board
AI_DATA_OUT_SCL: U11.97 (PA8); also elsewhere on the board
AI_DATA_OUT_SDA: U11.96 (PC9); also elsewhere on the board
AI_HOST_WAKEUP: U11.94 (PC7); also elsewhere on the board
AUDIO_CLK: R33.1; also elsewhere on the board
AUDIO_FSYNC: R35.1; also elsewhere on the board
AUDIO_SD: U11.61 (PE11); also elsewhere on the board
CELL_UART_CTS: U11.37 (PA0); also elsewhere on the board
CELL_UART_RTS: U11.38 (PA1); also elsewhere on the board
CELL_UART_RXD: U11.40 (PA3); also elsewhere on the board
CELL_UART_TXD: U11.39 (PA2); also elsewhere on the board
GND: C82.2, C83.2, C84.2, C85.2, C86.2, R36.2, Y3.2 (GND); also elsewhere on the board
GPS_NRESET: U11.44 (PA5); also elsewhere on the board
GPS_PWR_ON: U11.43 (PA4); also elsewhere on the board
GPS_TIMEPULSE: U11.60 (PE10); also elsewhere on the board
GPS_TIME_TRIGGER: U11.59 (PE9); also elsewhere on the board
GPS_UART_RXD: U11.57 (PE7); also elsewhere on the board
GPS_UART_TXD: U11.58 (PE8); also elsewhere on the board
IMU_INT: U11.133 (PB6); also elsewhere on the board
IMU_SCL: U11.136 (PB8); also elsewhere on the board
IMU_SDA: U11.134 (PB7); also elsewhere on the board
LED_GPS_STATUS: U11.50 (PB1); also elsewhere on the board
MCU_NRST: C85.1, U11.27 (NRST); also elsewhere on the board
MCU_SWDCLK: U11.107 (PA14); also elsewhere on the board
MCU_SWDIO: R34.1; also elsewhere on the board
MCU_SWO: R38.1; also elsewhere on the board
MICS_SCL: U11.66 (PB10); also elsewhere on the board
MICS_SDA: U11.67 (PB11); also elsewhere on the board
unnamed: R34.2, U11.102 (PA13)
unnamed: R38.2, U11.130 (PB3)
unnamed: C84.1, U11.10 (PC14-OSC32_IN), Y4.1
unnamed: C86.1, U11.11 (PC15-OSC32_OUT), Y4.2
unnamed: R36.1, U11.135 (BOOT0)
unnamed: R37.1, U11.142 (PDR_ON)
unnamed: R33.2, U11.62 (PE12)
unnamed: R35.2, U11.63 (PE13)
unnamed: R32.1, U11.25 (PH0-OSC_IN)
unnamed: R32.2, Y3.3 (OUTPUT)
USB_D+: U11.101 (PA12); also elsewhere on the board
USB_D-: U11.100 (PA11); also elsewhere on the board
VCC_MCU: R37.2; also elsewhere on the board
VCC_MCU_1V8: C82.1, C83.1, Y3.1 (~INH), Y3.4 (VDD); also elsewhere on the board

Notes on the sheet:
MCU Clocks and GPIO
MCU GPIO Banks E-G
MCU GPIO Banks A-D

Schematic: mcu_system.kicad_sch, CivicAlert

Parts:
C62, C76, C79: 4.7u; C_0402_1005Metric; MPN GRT155D70J475ME13D
C63, C64, C65, C66, C67, C68, C69, C70, C71, C72, C73, C74, C75, C77: 0.1u; C_0402_1005Metric; MPN GRM155R71C104KA88J
C78, C80, C81: 2.2u; C_0402_1005Metric; MPN GRT155C71A225KE13D
FL1: FCM 1608KF-601T03; FCM1608KF-601T03; MPN FCM1608KF-601T03
R28: 47; R_0402_1005Metric
U11: STM32H745ZIT6; MPN STM32H745ZIT6

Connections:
GND: C62.1, C63.1, C64.1, C65.1, C66.1, C67.1, C68.1, C69.2, C70.2, C71.2, C72.2, C73.2, C74.2, C75.2, C76.2, C77.1, C78.2, C79.2, C80.2, C81.2, U11.6 (VSS), U11.12 (VSS), U11.14 (VSSSMPS), U11.16 (VDDSMPS), U11.17 (VFBSMPS), U11.18 (VSS), U11.33 (VSS), U11.34 (VSSA), U11.41 (VSS), U11.55 (VSS), U11.69 (VSS), U11.80 (VSS), U11.89 (VSS), U11.104 (VSS), U11.118 (VSS), U11.128 (VSS), U11.141 (VSS); also elsewhere on the board
unnamed: C80.1, C81.1, U11.68 (VCAP), U11.103 (VCAP), U11.140 (VCAP)
unnamed: C78.1, U11.91 (VDD33USB)
unnamed: FL1.2, R28.1, U11.36 (VDDA)
unnamed: R28.2, U11.35 (VREF+)
VCC_5V: C79.1, U11.90 (VDD50USB); also elsewhere on the board
VCC_MCU: C62.2, C63.2, C64.2, C65.2, C66.2, C67.2, C68.2, C69.1, C70.1, C71.1, C72.1, C73.1, C74.1, C75.1, C76.1, C77.2, FL1.1, U11.7 (VDD), U11.8 (VBAT), U11.13 (VDD), U11.19 (VDD), U11.32 (VDD), U11.42 (VDD), U11.56 (VDD), U11.70 (VDDLDO), U11.71 (VDD), U11.79 (VDD), U11.92 (VDD), U11.105 (VDDLDO), U11.106 (VDD), U11.119 (VDD), U11.129 (VDD), U11.143 (VDDLDO), U11.144 (VDD); also elsewhere on the board

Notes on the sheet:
MCU System
MCU Power

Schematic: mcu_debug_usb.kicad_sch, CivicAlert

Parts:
B2: 009159010061911
C87, C88: 0.1u; C_0402_1005Metric; MPN GRM155R71C104KA88J
IC3: ESDALC6V1W5; MPN ESDALC6V1W5
J1: USB4730-GF-A_REVA; USB4730-GF-A; PARTREV A
R39, R40: 22; R_0402_1005Metric
R41, R42: 5.1k; R_0402_1005Metric

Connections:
GND: B2.6 (GND), C87.2, C88.2, IC3.2 (GND), J1.A1/B12 (GND_A), J1.B1/A12 (GND_B), J1.SH1 (SHELL_GND), J1.SH2 (SHELL_GND), J1.SH3 (SHELL_GND), J1.SH4 (SHELL_GND), R41.1, R42.1; also elsewhere on the board
MCU_NRST: B2.9 (NRST), IC3.5 (I/04); also elsewhere on the board
MCU_SWDCLK: IC3.4 (I/03), R40.1; also elsewhere on the board
MCU_SWDIO: IC3.3 (I/02), R39.1; also elsewhere on the board
MCU_SWO: B2.5 (JTDO/SWO), IC3.1 (I/01); also elsewhere on the board
unnamed: B2.4 (JCLK/SWCLK), R40.2
unnamed: B2.3 (JTMS/SWDIO), R39.2
unnamed: J1.A5 (CC1), R41.2
unnamed: J1.B5 (CC2), R42.2
USB_D+: J1.A6 (DP1), J1.B6 (DP2); also elsewhere on the board
USB_D-: J1.A7 (DN1), J1.B7 (DN2); also elsewhere on the board
VCC_5V: C87.1, C88.1, J1.A4/B9 (VBUS_A), J1.B4/A9 (VBUS_B); also elsewhere on the board
VCC_MCU_1V8: B2.10 (VCC); also elsewhere on the board

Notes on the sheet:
USB-C Power + Aux Data Output
MCU Debug + USB
MCU JTAG/SWD Connector

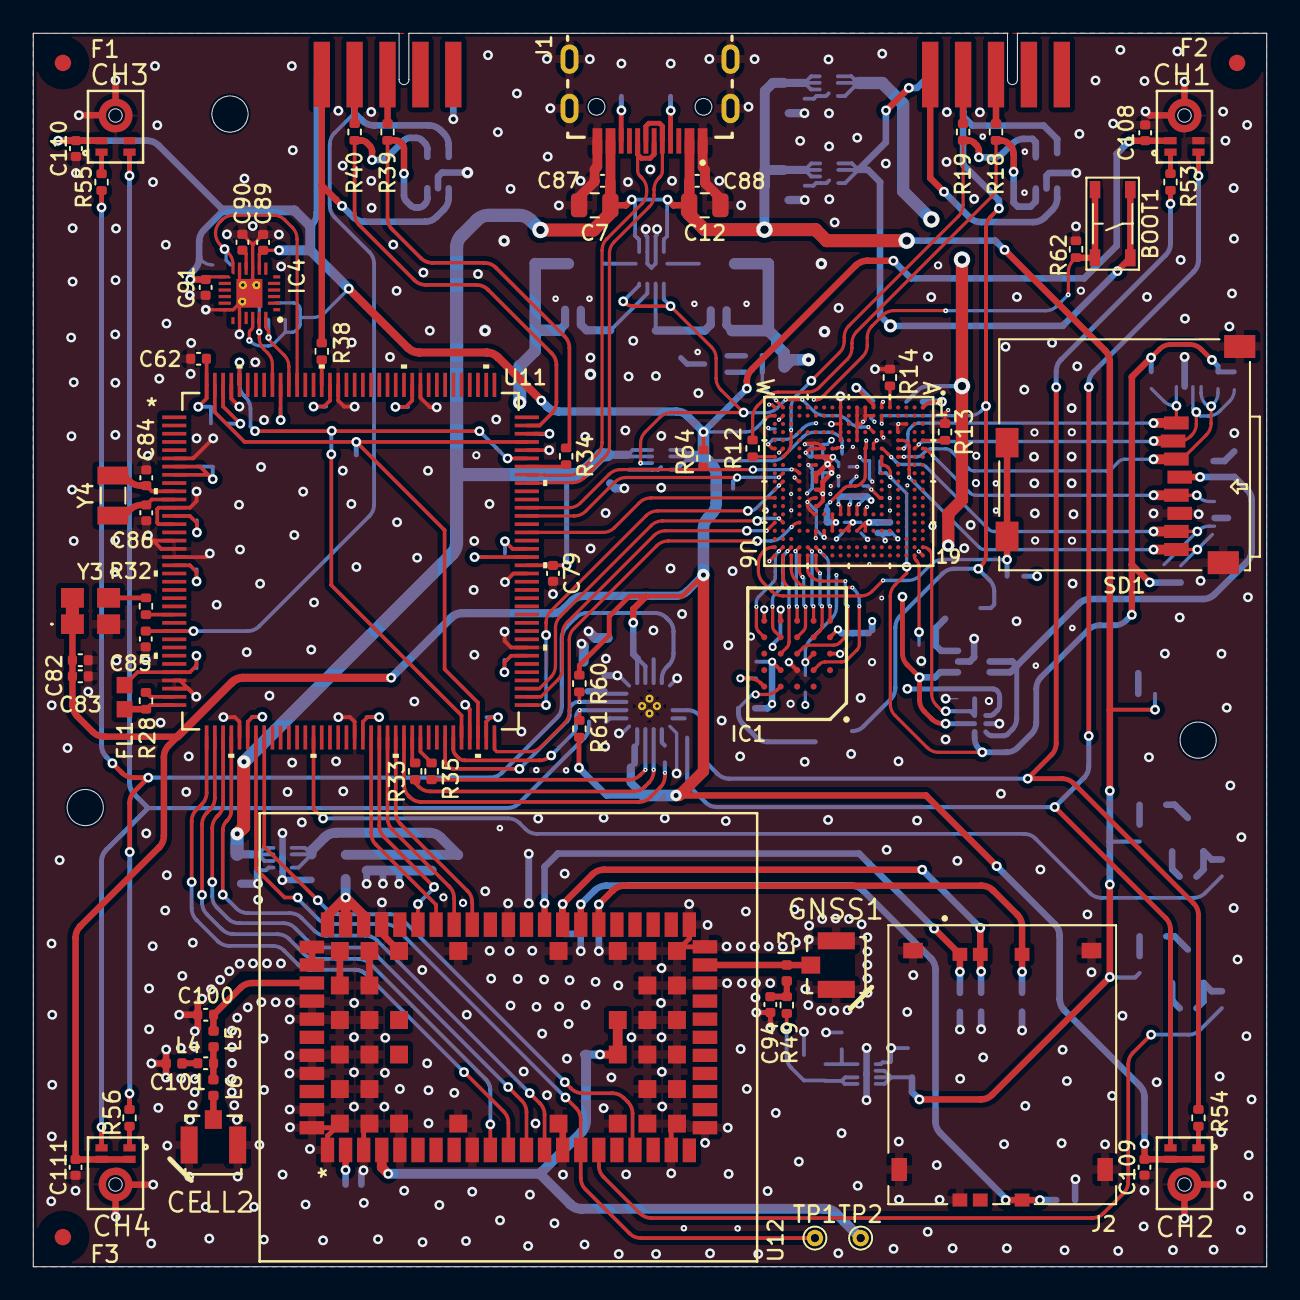
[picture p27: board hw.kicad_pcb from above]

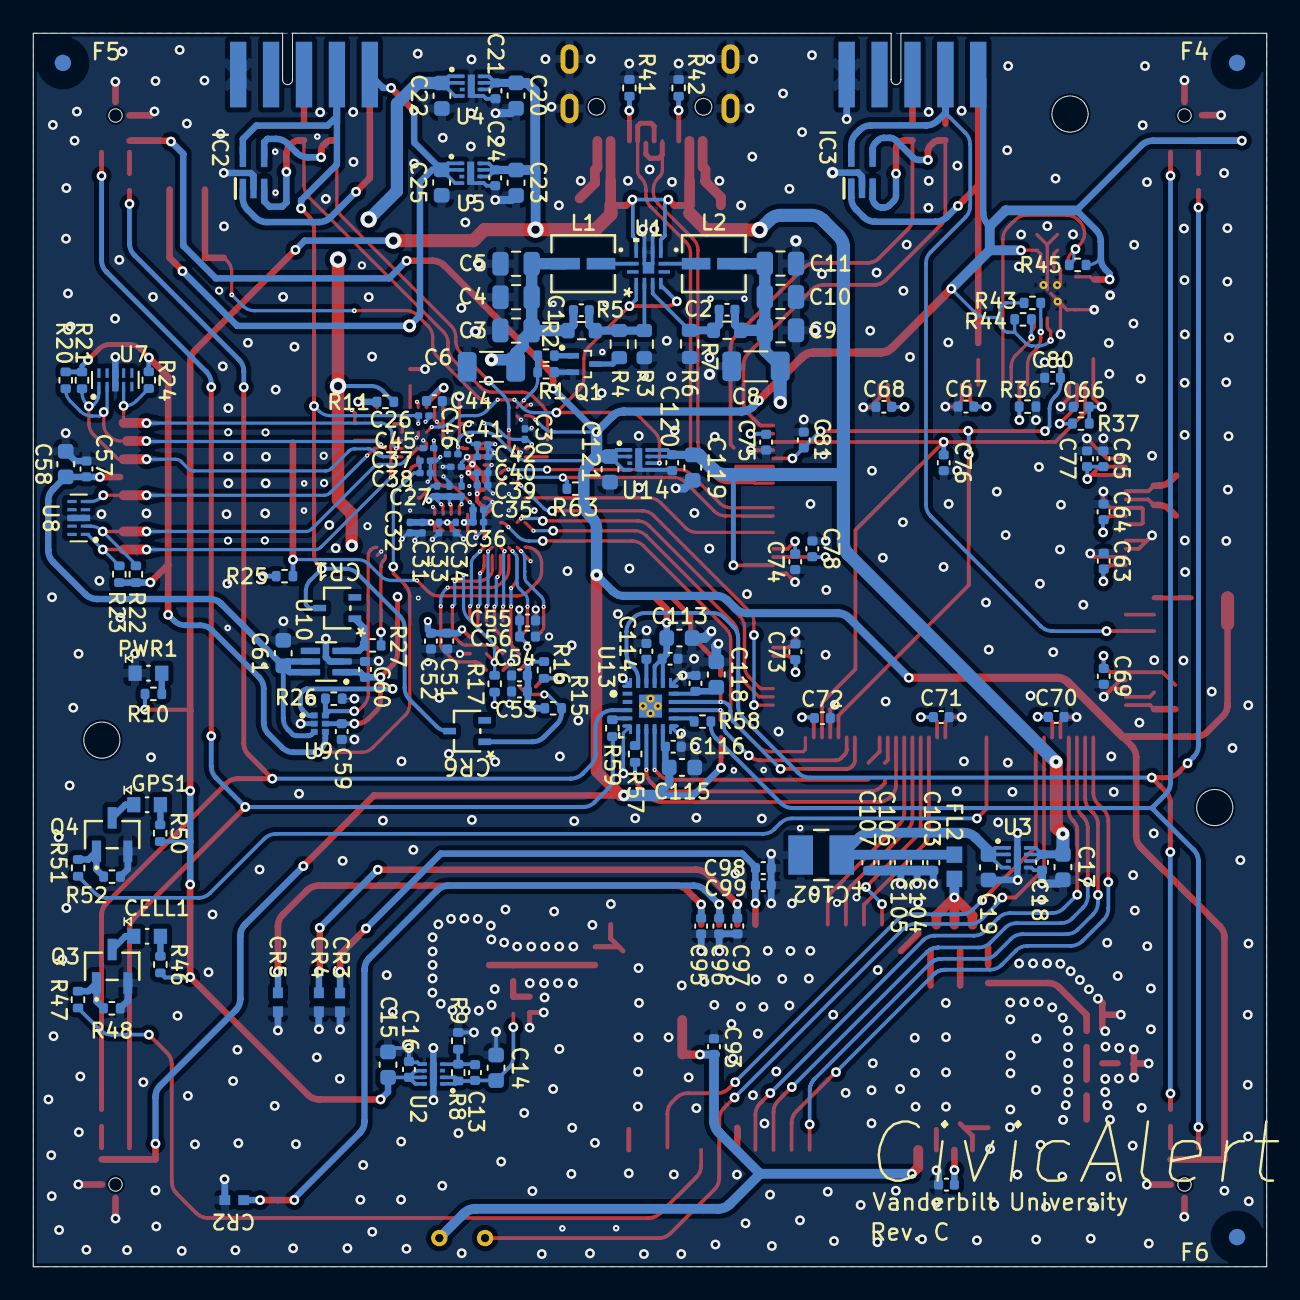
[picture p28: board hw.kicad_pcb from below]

Board: 4 copper layers, 75.0 x 75.0 mm, 241 parts (166 on the bottom side), 140 nets.

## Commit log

2025-06-16 Initial Commit (Rev. A)
    [10164227-1004a1rlf.step, 788000001.step, ATX-H11-F-25.000MHz-F25-T.step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]
2025-06-17 Add cathode marker to footprint
2025-06-17 Fix RF trace impedances
    [hw.kicad_pcb]
2025-06-23 Update silkscreen, add modem +5V via to regulator
    [gps_cellular.kicad_sch, hw.kicad_pcb]
2025-07-31 New structure for holding parts, symbols, and footprints
    [0788000001.step, 10164227-1004A1RLF.step, ATX-H11-F-25_000MHz-F25-T.step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]
2025-08-01 Update documentation and images
    [hw.kicad_pcb]
2025-09-10 Update for RevB
    [10164227-1004A1RLF.step, 15882.step, ABS07AIG-32.768KHZ-7-T.step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]
2025-09-15 Finalize RevB
    [PTS810S.step, ai_gpio.kicad_sch, ai_memory.kicad_sch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]
2025-09-16 Fix wrong silkscreen layout for flash chp
    [MX25UM25645GXDI00.step]
2025-09-16 Add fiducials
    [gps_cellular.kicad_sch, hw.kicad_pcb]
2025-11-15 Updates for Rev. C
    [USB4730-GF-A.step, ai_gpio.kicad_sch, ai_memory.kicad_sch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]
2025-11-20 Update RevC design
    [RevC-BOM-MacroFab.xlsx, SI1062X-T1-GE3.step, ai_gpio.kicad_sch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]
2026-03-02 Connect VREF+ to GND instead of VCC_1.8
    [ai_system.kicad_sch]
